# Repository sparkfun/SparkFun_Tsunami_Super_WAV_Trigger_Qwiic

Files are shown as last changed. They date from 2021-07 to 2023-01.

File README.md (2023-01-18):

SparkFun Tsunami Super WAV Trigger (Qwiic)
========================================

<table class="table table-hover table-striped table-bordered">
  <tr align="center">
   <td><a href="https://www.sparkfun.com/products/18159">SparkFun Tsunami Super WAV Trigger (Qwiic) -32 Voices</a></td>
   <td><a href="https://www.sparkfun.com/products/20636">SparkFun Tsunami Super WAV Trigger (Qwiic) - 25 Voices</a></td>
  </tr>
  <tr align="center">
   <td><i>SparkFun Tsunami Super WAV Trigger (Qwiic)<br /> - 32 Voices <br />[ <a href="https://www.sparkfun.com/products/18159">WIG-18159</a> ]</i></td>
   <td><i>SparkFun Tsunami Super WAV Trigger (Qwiic)<br /> - 25 Voices <br />[ <a href="https://www.sparkfun.com/products/20636">WIG-20636</a> ]</i></td>
  </tr>
</table>

Tsunami is a polyphonic Wav file player with 4 stereo (or 8 mono) outputs.  Wav files can be triggered using the 16 onboard contacts, via MIDI, serial connection or Qwiic to a PC or other microcontroller.

Repository Contents
-------------------

* **/Documentation** - Data sheets, additional product information
* **/Hardware** - Eagle design files (.brd, .sch)
* **/Production** - Production panel files (.brd)
* **/Example_WAV_files/MONO** - example WAV Files for use with _mono_ firmware and the [Qwiic Arduino Library Examples](https://github.com/sparkfun/SparkFun_Tsunami_Qwiic_Arduino_Library).
* **/Example_WAV_files/STEREO** - example WAV Files for use with _stereo_ firmware

Documentation
--------------
* **[Hookup Guide](https://learn.sparkfun.com/tutorials/tsunami-super-wav-trigger-hookup-guide)** - Basic hookup guide for Tsunami Qwiic.
* **[Official User Guide](https://cdn.sparkfun.com/assets/e/9/9/8/e/Tsunami_UserGuide_20230114.pdf)** - More detailed user guide, written by Robertsonics.
* **[Official Downloads Page](http://robertsonics.com/downloads/)** - Download supporting files, including firmware updates and the configuration utility.
* **[SparkFun Tsunami Qwiic Arduino Library](https://github.com/sparkfun/SparkFun_Tsunami_Qwiic_Arduino_Library)** - Arduino Library for I2C control via Qwiic cable.
* **[Tsunami Arduino Serial Library](https://github.com/robertsonics/Tsunami-Arduino-Serial-Library)** - Arduino Library for Serial interface control via RX/TX.
* **[SparkFun Fritzing repo](https://github.com/sparkfun/Fritzing_Parts/blob/main/products/13810_Tsunami_Super_WAV_Trigger.fzpz)** - Fritzing diagrams for SparkFun products.
* **[SparkFun 3D Model repo](https://github.com/sparkfun/3D_Models)** - 3D models of SparkFun products.

Product Versions
----------------
* [WIG-20636](https://www.sparkfun.com/products/20636) - v21 with ATSAMS70N19, 25 Voices, and Qwiic supported! 
* [WIG-18159](https://www.sparkfun.com/products/18159) - v21 with ATSAMS70N20, 32 Voices, and Qwiic supported! 
* [WIG-13810](https://www.sparkfun.com/products/13810) - v11 First hardware revision (non-qwiic)

Version History
---------------
* [v21 Production Release](https://github.com/sparkfun/SparkFun_Tsunami_Super_WAV_Trigger_Qwiic/commit/4bed2473d8b69c6fbc46fcfe248d6b1637192635) - V21 hardware revision. There are different versions of this board that use the same PCB. To distinguish the two, check out the IC: ATSAMS70N20 for 32 voices and ATSAMS70N19 for 25 voices.
* [v11 Initial production Release](https://github.com/sparkfun/tsunami/commit/f42b14d72773535e83374cde73f2ca3f25164abb) - V11 hardware revision.

License Information
-------------------

The hardware design of Tsunami is _**open source**_!

Please review the LICENSE.md file for license information.

If you have any questions or concerns on licensing, please contact techsupport@sparkfun.com.

Distributed as-is; no warranty is given.

- Your friends at SparkFun.

Authors
----

Jamie Robertson @ Robertsonics, 
Pete Lewis @ SparkFun Electronics, 
Byron Jacquot @ SparkFun Electronics

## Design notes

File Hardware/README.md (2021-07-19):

SparkFun <PRODUCT NAME> Design Files
=====================================

The .sch and .brd files hare are Eagle CAD schematic and PCB design files from SparkFun Electronics.
A freeware version of Eagle can be found [here](http://www.cadsoftusa.com/download-eagle/freeware/).

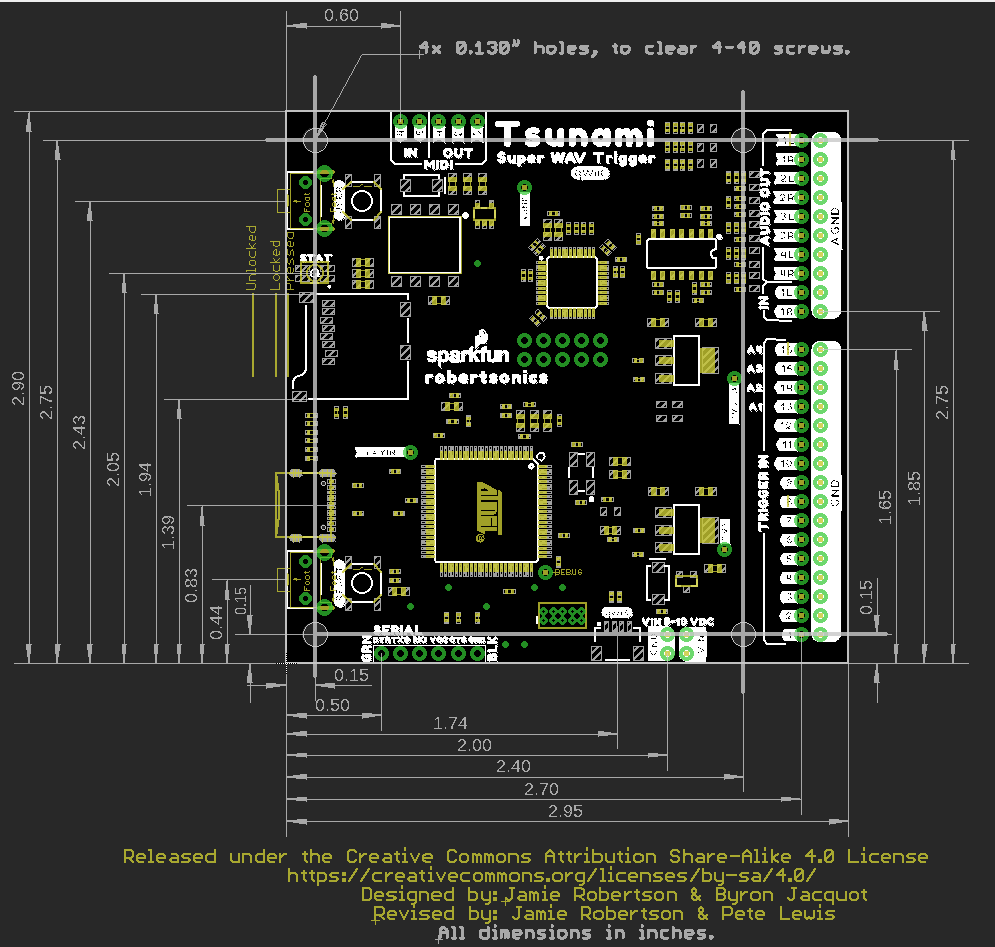
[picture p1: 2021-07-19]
Documents/SparkFun_Tsunami_Qwiic_DIMENSIONS.png

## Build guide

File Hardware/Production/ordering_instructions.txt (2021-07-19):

panel size, 255x162mm
PCB thickness, 1.6mm
number of layers, 2
soldermask color, Red
silkscreen color, White
oz copper, 1oz
finish, HASL lead free
stencils, top
pcs per panel, 6
min trace width, 0.2032mm / 0.0080in
min drill size, 0.3048mm / 0.0120in

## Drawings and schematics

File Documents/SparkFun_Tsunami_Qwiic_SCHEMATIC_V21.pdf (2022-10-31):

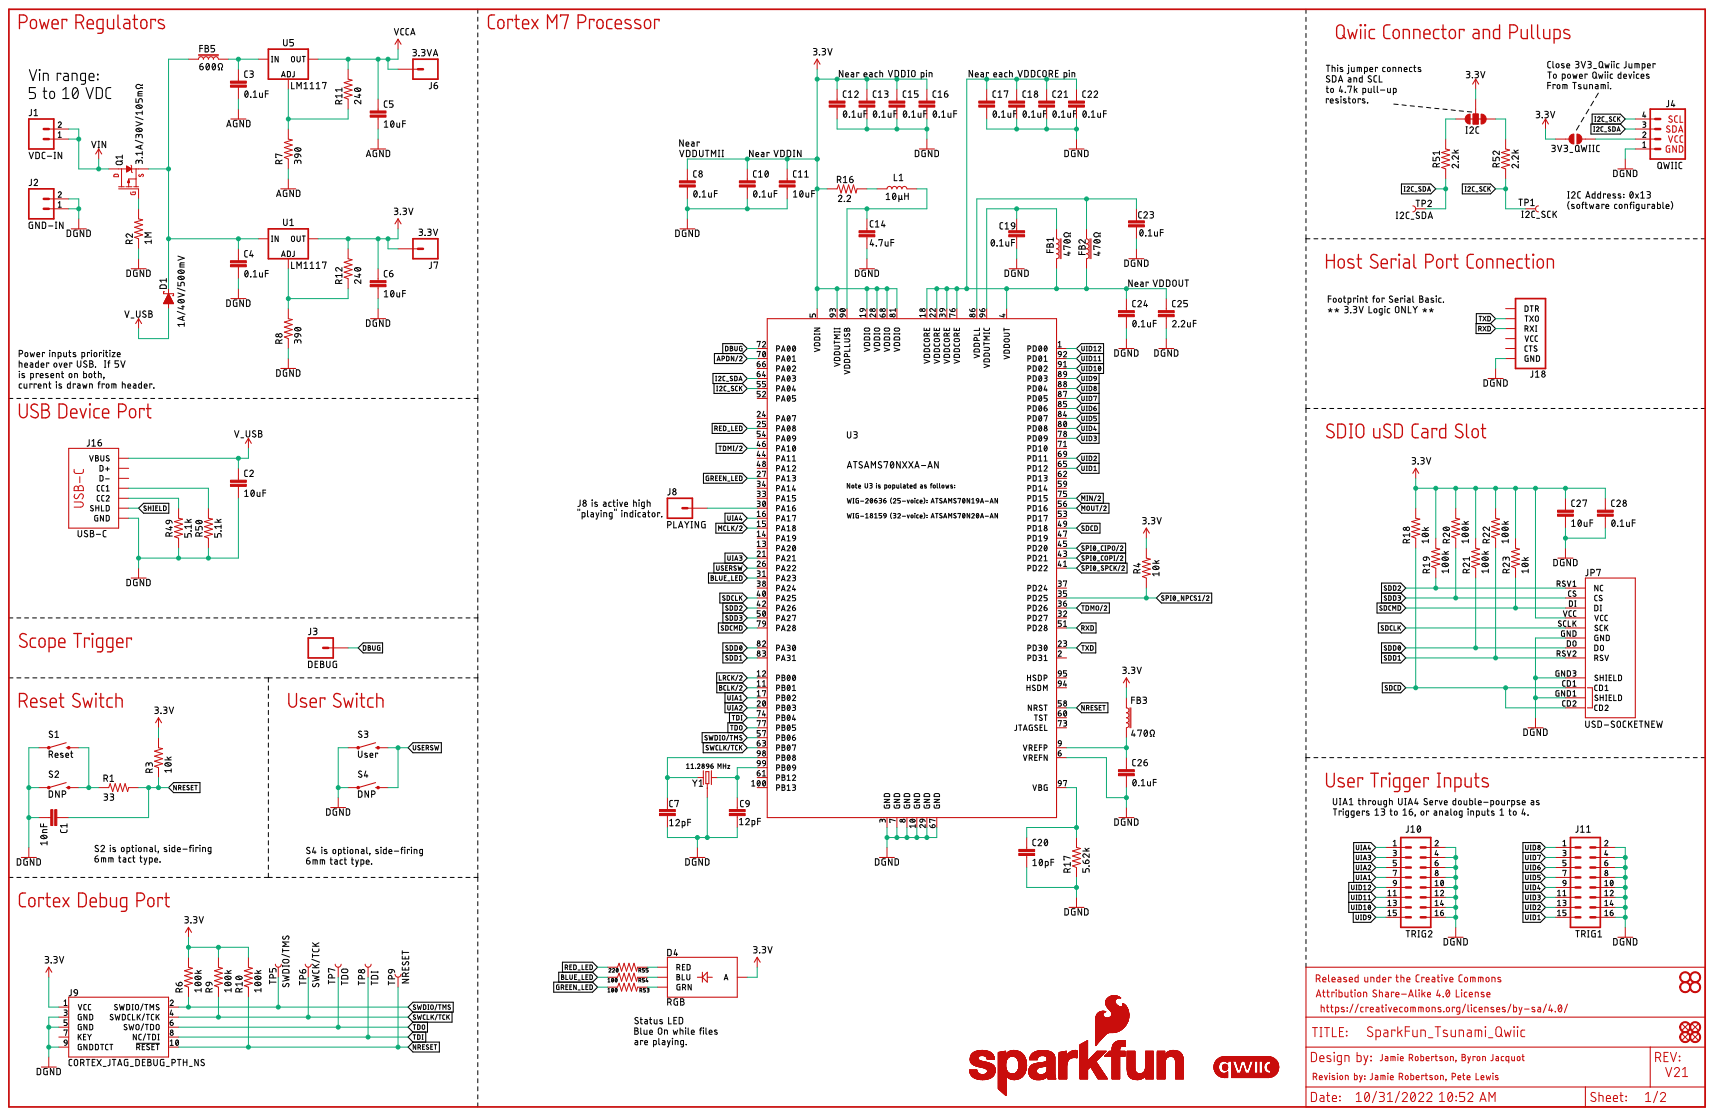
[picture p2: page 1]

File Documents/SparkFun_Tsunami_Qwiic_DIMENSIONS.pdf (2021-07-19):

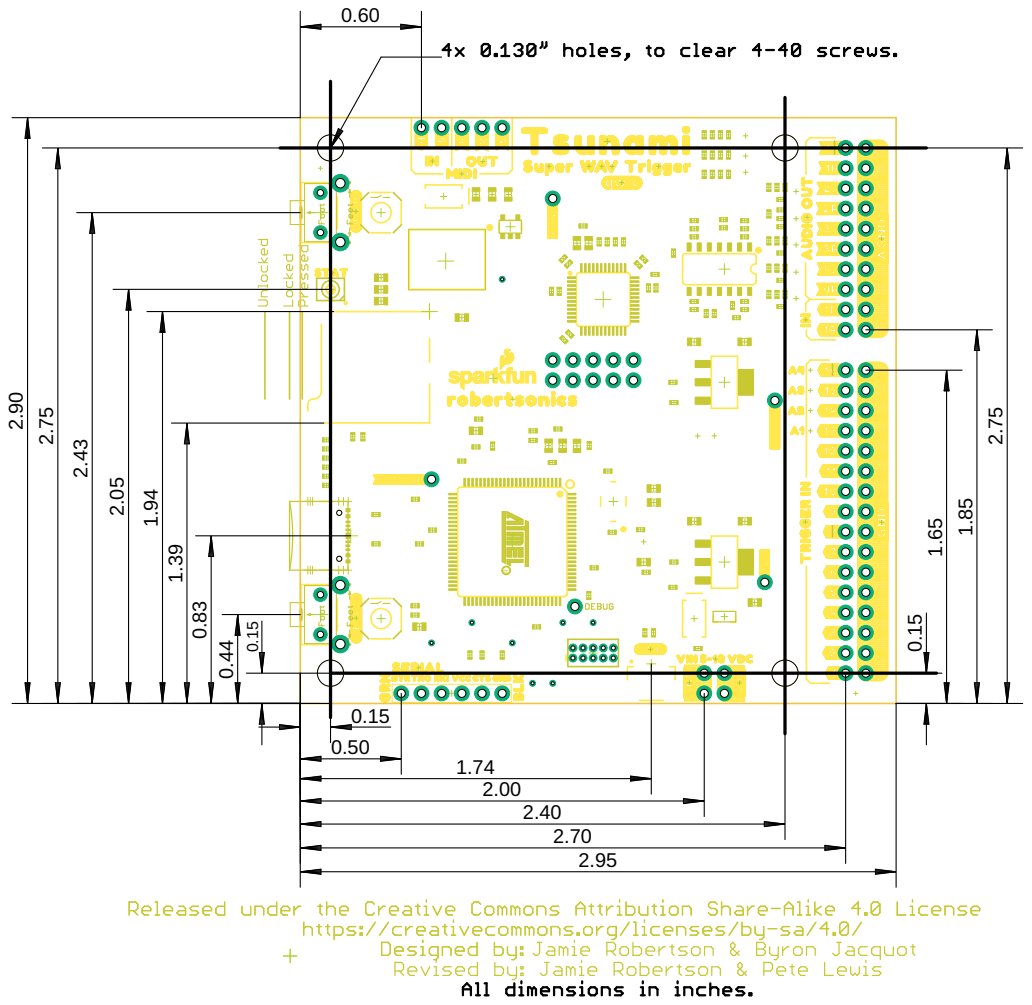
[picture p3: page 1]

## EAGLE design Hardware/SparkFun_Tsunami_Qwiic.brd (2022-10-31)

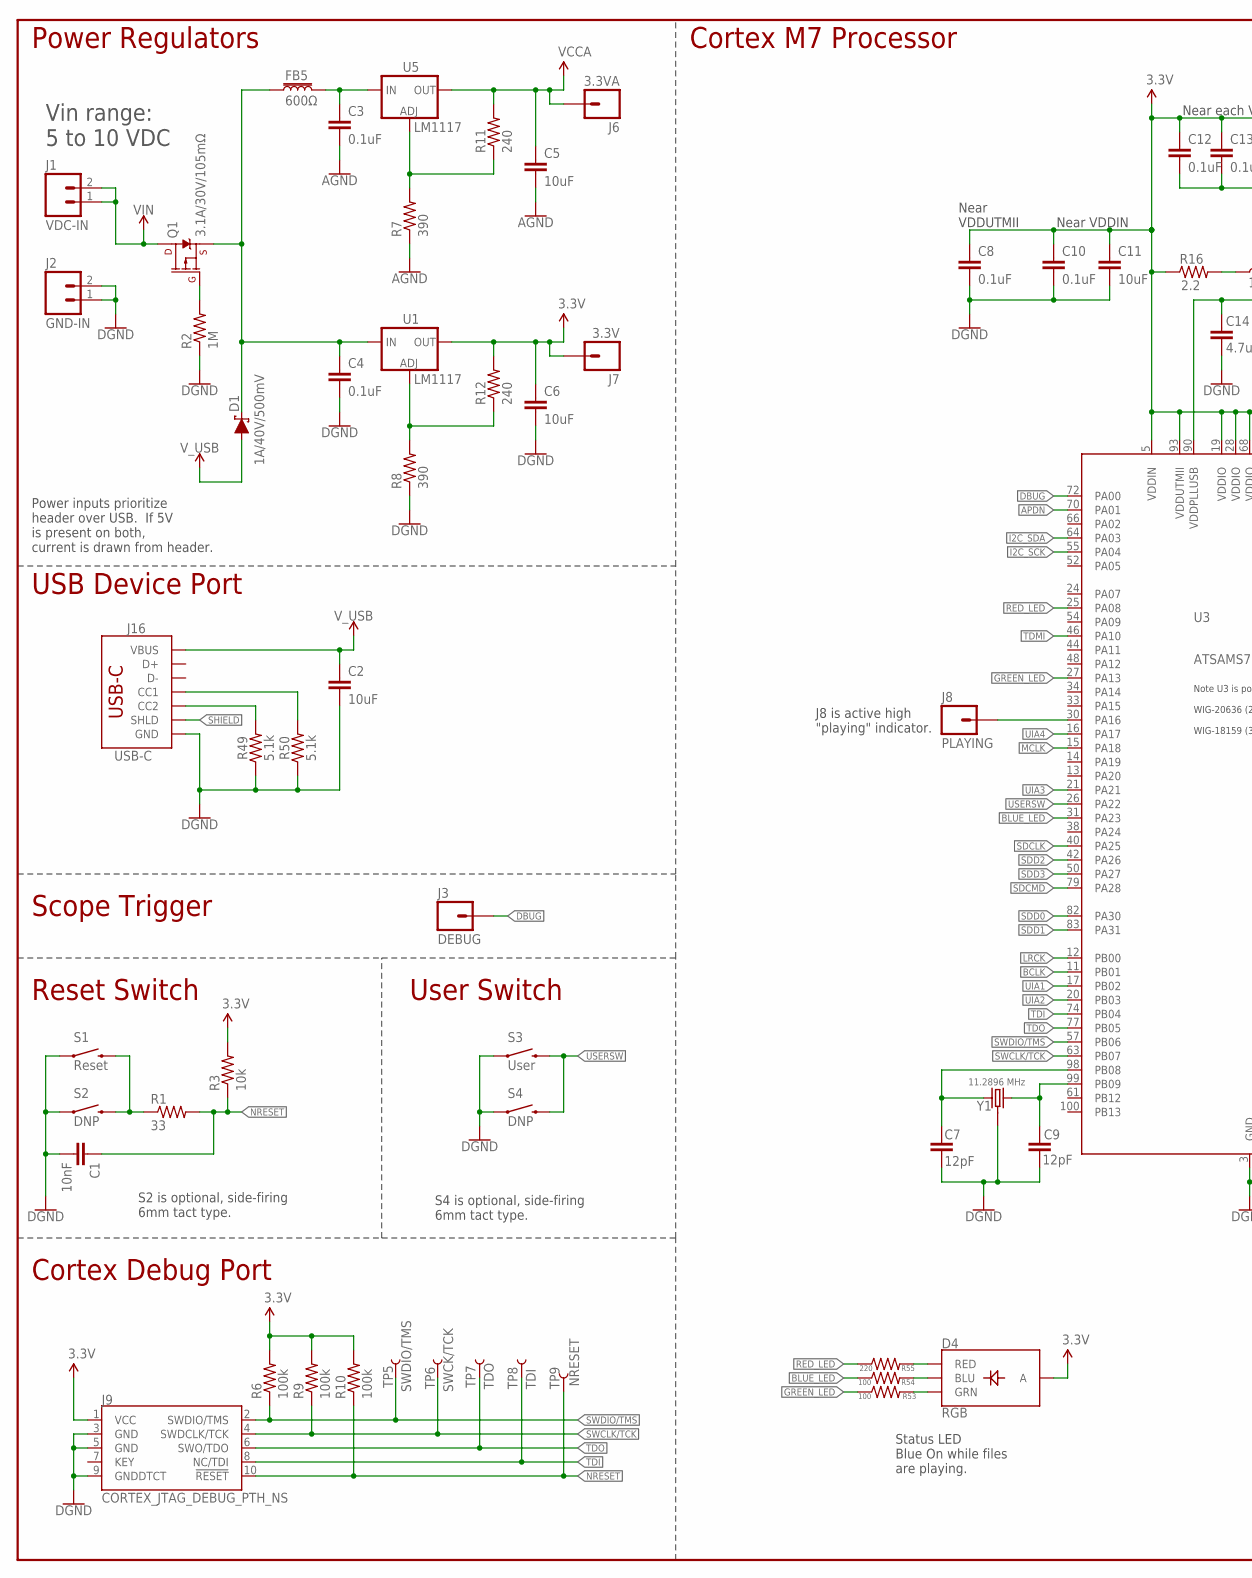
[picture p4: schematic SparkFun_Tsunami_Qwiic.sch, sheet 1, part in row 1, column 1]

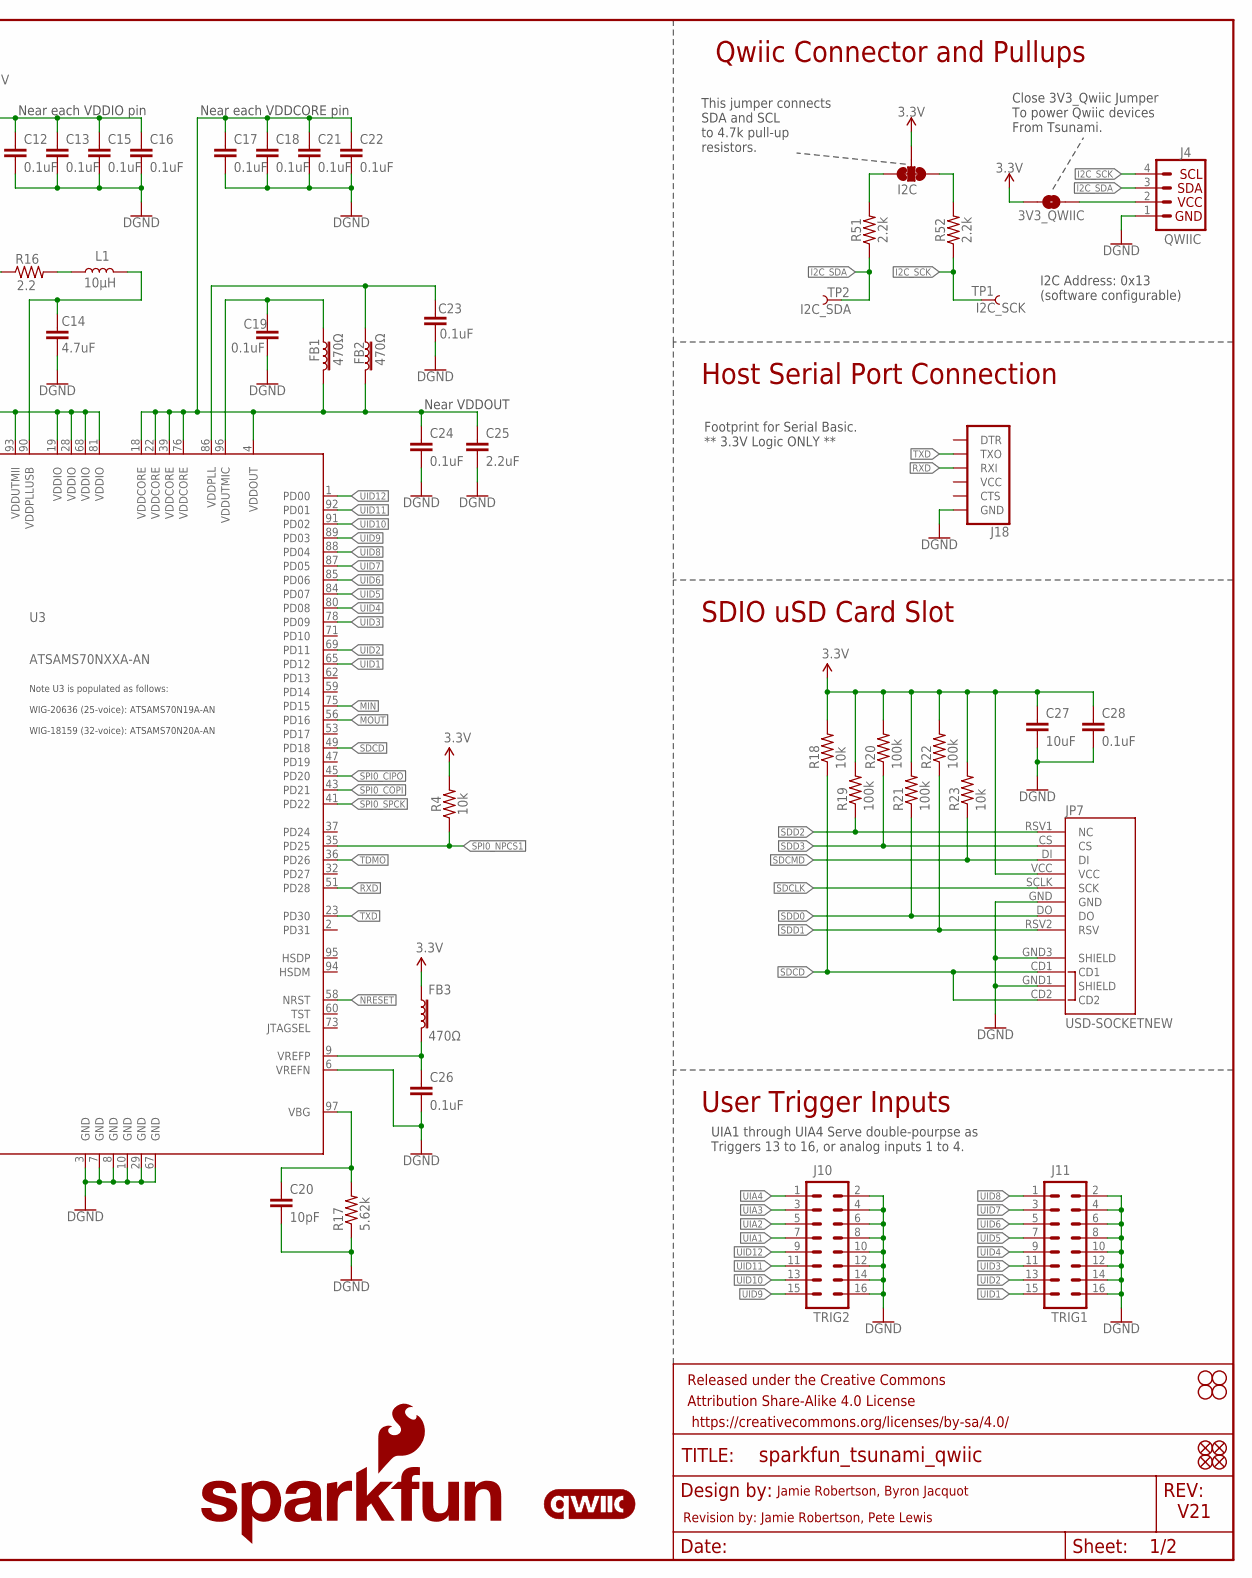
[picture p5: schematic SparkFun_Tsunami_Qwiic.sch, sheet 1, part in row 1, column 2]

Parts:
3V3_QWIIC: JUMPER-SMT_2_NO_SILK; SMT-JUMPER_2_NO_SILK
C1: 10nF; 0402-TIGHT
C2, C5, C6, C11, C27: 10uF; 0402-TIGHT
C3, C4, C8, C10, C12, C13, C15, C16, C17, C18, C19, C21, C22, C23, C24, C26, C28: 0.1uF; 0402-TIGHT
C7, C9: 12pF; 0402-TIGHT
C14: 4.7uF; 0402-TIGHT
C20: 10pF; 0603
C25: 2.2uF; 0603
D1: 1A/40V/500mV; SMA-DIODE
D4: RGB; P-LCC-4-3
FB1, FB2, FB3: 470Ω; 0603
FB5: 600Ω; 0805
FD1, FD2, FD3, FD4: FIDUCIALUFIDUCIAL; FIDUCIAL-MICRO
FRAME1: FRAME-LEDGER; CREATIVE_COMMONS
H1, H2, H3, H4: STAND-OFF
I2C: JUMPER-SMT_3_2-NC_TRACE_SILK; SMT-JUMPER_3_2-NC_TRACE_SILK
J1: VDC-IN; 1X02_NO_SILK
J2: GND-IN; 1X02_NO_SILK
J3: DEBUG; 1X01_NO_SILK
J4: QWIIC; JST04_1MM_RA
J6: 3.3VA; 1X01_NO_SILK
J7: 3.3V; 1X01_NO_SILK
J8: PLAYING; 1X01_NO_SILK
J9: CORTEX_JTAG_DEBUG_PTH_NS; 2X5-PTH-1.27MM-NO_SILK
J10: TRIG2; 2X8_NOSILK
J11: TRIG1; 2X8_NOSILK
J16: USB-C; USB-C-16P-4LAYER-ISOLATED
J18: 6_PIN_SERIAL_TARGETSILK; 6_PIN_SERIAL_TARGET_SIDE_W_SILK
JP7: USD-SOCKETNEW; MICRO-SD-SOCKET-PP
L1: 10μH; 0805
LOGO2: SFE_LOGO_NAME_FLAME.2_INCH; SFE_LOGO_NAME_FLAME_.2
LOGO3: QWIIC_LOGO_4MM; QWIIC_4MM
Q1: 3.1A/30V/105mΩ; SOT23-3
R1: 33; 0603
R2: 1M; 0603
R3, R4, R18, R23: 10k; 0402-TIGHT
R6, R9, R10, R19, R20, R21, R22: 100k; 0402-TIGHT
R7, R8: 390; 0603
R11, R12: 240; 0603
R16: 2.2; 0603
R17: 5.62k; 0603
R49, R50: 5.1k; 0402-TIGHT
R51, R52: 2.2k; 0402-TIGHT
R53, R54: 100; 0603
R55: 220; 0603
S1: Reset; TACTILE_SWITCH_SMD_5.2MM
S2, S4: DNP; TACTILE_SWITCH_PTH_RIGHT_ANGLE
S3: User; TACTILE_SWITCH_SMD_5.2MM
TP1: I2C_SCK; TP_15TH
TP2: I2C_SDA; TP_15TH
TP5: SWDIO/TMS; TP_15TH
TP6: SWCK/TCK; TP_15TH
TP7: TDO; TP_15TH
TP8: TDI; TP_15TH
TP9: NRESET; TP_15TH
U1, U5: LM1117; SOT223
U3: ATSAMS70NXXA-AN; LQFP100
Y1: 11.2896 MHz; CRYSTAL-OSC-SMD-5X3

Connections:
3.3V: 3V3_QWIIC.1, C6.1, C8.1, C10.1, C11.1, C12.1, C13.1, C15.1, C16.1, C27.1, C28.1, D4.4 (A), FB3.1, I2C.2, J7.1, J9.1 (VCC), JP7.VCC, R3.2, R4.2, R6.2, R9.2, R10.2, R12.2, R16.1, R18.2, R19.2, R20.2, R21.2, R22.2, R23.2, U1.2 (OUT), U1.4 (OUT), U3.5 (VDDIN), U3.19 (VDDIO), U3.28 (VDDIO), U3.68 (VDDIO), U3.81 (VDDIO), U3.93 (VDDUTMII); also elsewhere on the board
AGND: C3.2, C5.2, R7.1; also elsewhere on the board
APDN: U3.70 (PA01); also elsewhere on the board
BCLK: U3.11 (PB01); also elsewhere on the board
BLUE_LED: R54.1, U3.31 (PA23)
CC1: J16.A5 (CC1), R50.2
CC2: J16.B5 (CC2), R49.2
DBUG: J3.1, U3.72 (PA00)
DGND: C1.2, C2.2, C4.2, C6.2, C7.2, C8.2, C9.2, C10.2, C11.2, C12.2, C13.2, C14.2, C15.2, C16.2, C17.2, C18.2, C19.2, C20.2, C21.2, C22.2, C23.2, C24.2, C25.2, C26.2, C27.2, C28.2, J2.1, J2.2, J4.1, J9.3 (GND), J9.5 (GND), J9.9 (GNDDTCT), J10.2, J10.4, J10.6, J10.8, J10.10, J10.12, J10.14, J10.16, J11.2, J11.4, J11.6, J11.8, J11.10, J11.12, J11.14, J11.16, J16.GND, J16.GND2 (GND), J18.6 (GND), JP7.GND, JP7.GND1 (SHIELD), JP7.GND3 (SHIELD), R2.1, R8.1, R17.1, R49.1, R50.1, S1.1, S2.1, S3.1, S4.1, U3.3 (GND), U3.6 (VREFN), U3.7 (GND), U3.8 (GND), U3.10 (GND), U3.29 (GND), U3.67 (GND), Y1.2 (3), Y1.4 (3); also elsewhere on the board
GREEN_LED: R53.1, U3.27 (PA13)
I2C_SCK: J4.4, R52.1, TP1.1, U3.55 (PA04)
I2C_SDA: J4.3, R51.1, TP2.1, U3.64 (PA03)
LRCK: U3.12 (PB00); also elsewhere on the board
MCLK: U3.15 (PA18); also elsewhere on the board
MIN: U3.75 (PD15); also elsewhere on the board
MOUT: U3.56 (PD16); also elsewhere on the board
unnamed: C7.1, U3.98 (PB08), Y1.1
unnamed: C9.1, U3.99 (PB09), Y1.3 (2)
unnamed: C19.1, FB1.1, U3.96 (VDDUTMIC)
unnamed: C14.1, L1.2, U3.90 (VDDPLLUSB)
unnamed: C23.1, FB2.1, U3.86 (VDDPLL)
unnamed: I2C.3, R51.2
unnamed: J8.1, U3.30 (PA16)
unnamed: I2C.1, R52.2
unnamed: C20.1, R17.2, U3.97 (VBG)
unnamed: C26.1, FB3.2, U3.9 (VREFP)
unnamed: L1.1, R16.2
unnamed: R7.2, R11.1, U5.1 (ADJ)
unnamed: R1.1, S1.3 (2), S2.2
unnamed: R8.2, R12.1, U1.1 (ADJ)
unnamed: 3V3_QWIIC.2, J4.2
unnamed: D4.2 (GRN), R53.2
unnamed: D4.3 (BLU), R54.2
unnamed: D4.1 (RED), R55.2
unnamed: C3.1, FB5.2, U5.3 (IN)
unnamed: Q1.1 (G), R2.2
NRESET: C1.1, J9.10 (!RESET), R1.2, R3.1, R10.1, TP9.1, U3.58 (NRST)
RED_LED: R55.1, U3.25 (PA08)
REGINPUTS: C4.1, D1.C, FB5.1, Q1.2 (S), U1.3 (IN)
RXD: J18.3 (RXI), U3.51 (PD28)
SDCD: JP7.CD1, JP7.CD2, R18.1, U3.49 (PD18)
SDCLK: JP7.SCLK (SCK), U3.40 (PA25)
SDCMD: JP7.DI, R23.1, U3.79 (PA28)
SDD0: JP7.DO, R21.1, U3.82 (PA30)
SDD1: JP7.RSV2 (RSV), R22.1, U3.83 (PA31)
SDD2: JP7.RSV1 (NC), R19.1, U3.42 (PA26)
SDD3: JP7.CS, R20.1, U3.50 (PA27)
SHIELD: J16.SHLD1 (SHLD), J16.SHLD2 (SHLD), J16.SHLD3 (SHLD), J16.SHLD4 (SHLD), J16.SHLD5 (SHLD), J16.SHLD6 (SHLD), J16.SHLD7 (SHLD), J16.SHLD8 (SHLD)
SPI0_CIPO: U3.45 (PD20); also elsewhere on the board
SPI0_COPI: U3.43 (PD21); also elsewhere on the board
SPI0_NPCS1: R4.1, U3.35 (PD25); also elsewhere on the board
SPI0_SPCK: U3.41 (PD22); also elsewhere on the board
SWCLK/TCK: J9.4 (SWDCLK/TCK), R9.1, TP6.1, U3.63 (PB07)
SWDIO/TMS: J9.2 (SWDIO/TMS), R6.1, TP5.1, U3.57 (PB06)
TDI: J9.8 (NC/TDI), TP8.1, U3.74 (PB04)
TDMI: U3.46 (PA10); also elsewhere on the board
TDMO: U3.36 (PD26); also elsewhere on the board
TDO: J9.6 (SWO/TDO), TP7.1, U3.77 (PB05)
TXD: J18.2 (TXO), U3.23 (PD30)
UIA1: J10.7, U3.17 (PB02)
UIA2: J10.5, U3.20 (PB03)
UIA3: J10.3, U3.21 (PA21)
UIA4: J10.1, U3.16 (PA17)
UID1: J11.15, U3.65 (PD12)
UID2: J11.13, U3.69 (PD11)
UID3: J11.11, U3.78 (PD09)
UID4: J11.9, U3.80 (PD08)
UID5: J11.7, U3.84 (PD07)
UID6: J11.5, U3.85 (PD06)
UID7: J11.3, U3.87 (PD05)
UID8: J11.1, U3.88 (PD04)
UID9: J10.15, U3.89 (PD03)
UID10: J10.13, U3.91 (PD02)
UID11: J10.11, U3.92 (PD01)
UID12: J10.9, U3.1 (PD00)
USERSW: S3.3 (2), S4.2, U3.26 (PA22)
VCCA: C5.1, J6.1, R11.2, U5.2 (OUT), U5.4 (OUT); also elsewhere on the board
VDDOUT: C17.1, C18.1, C21.1, C22.1, C24.1, C25.1, FB1.2, FB2.2, U3.4 (VDDOUT), U3.18 (VDDCORE), U3.22 (VDDCORE), U3.39 (VDDCORE), U3.76 (VDDCORE)
VIN: J1.1, J1.2, Q1.3 (D)
V_USB: C2.1, D1.A, J16.VBUS1 (VBUS), J16.VBUS2 (VBUS)

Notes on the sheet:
Jamie Robertson, Byron Jacquot
V21
Near each VDDCORE pin
Near each VDDIO pin
Near VDDUTMII
Near VDDIN
Near VDDOUT
Power Regulators
USB Device Port
Scope Trigger
Cortex Debug Port
Cortex M7 Processor
SDIO uSD Card Slot
User Trigger Inputs
Reset Switch
S2 is optional, side-firing 6mm tact type.
Vin range: 5 to 10 VDC
Status LED Blue On while files are playing.
Power inputs prioritize header over USB. If 5V is present on both, current is drawn from header.
UIA1 through UIA4 Serve double-pourpse as Triggers 13 to 16, or analog inputs 1 to 4.
Host Serial Port Connection
Footprint for Serial Basic. ** 3.3V Logic ONLY **
User Switch
J8 is active high "playing" indicator.
S4 is optional, side-firing 6mm tact type.
This jumper connects SDA and SCL to 4.7k pull-up resistors.
Revision by: Jamie Robertson, Pete Lewis
Qwiic Connector and Pullups
Close 3V3_Qwiic Jumper To power Qwiic devices From Tsunami.
I2C Address: 0x13 (software configurable)
Note U3 is populated as follows: WIG-20636 (25-voice): ATSAMS70N19A-AN WIG-18159 (32-voice): ATSAMS70N20A-AN

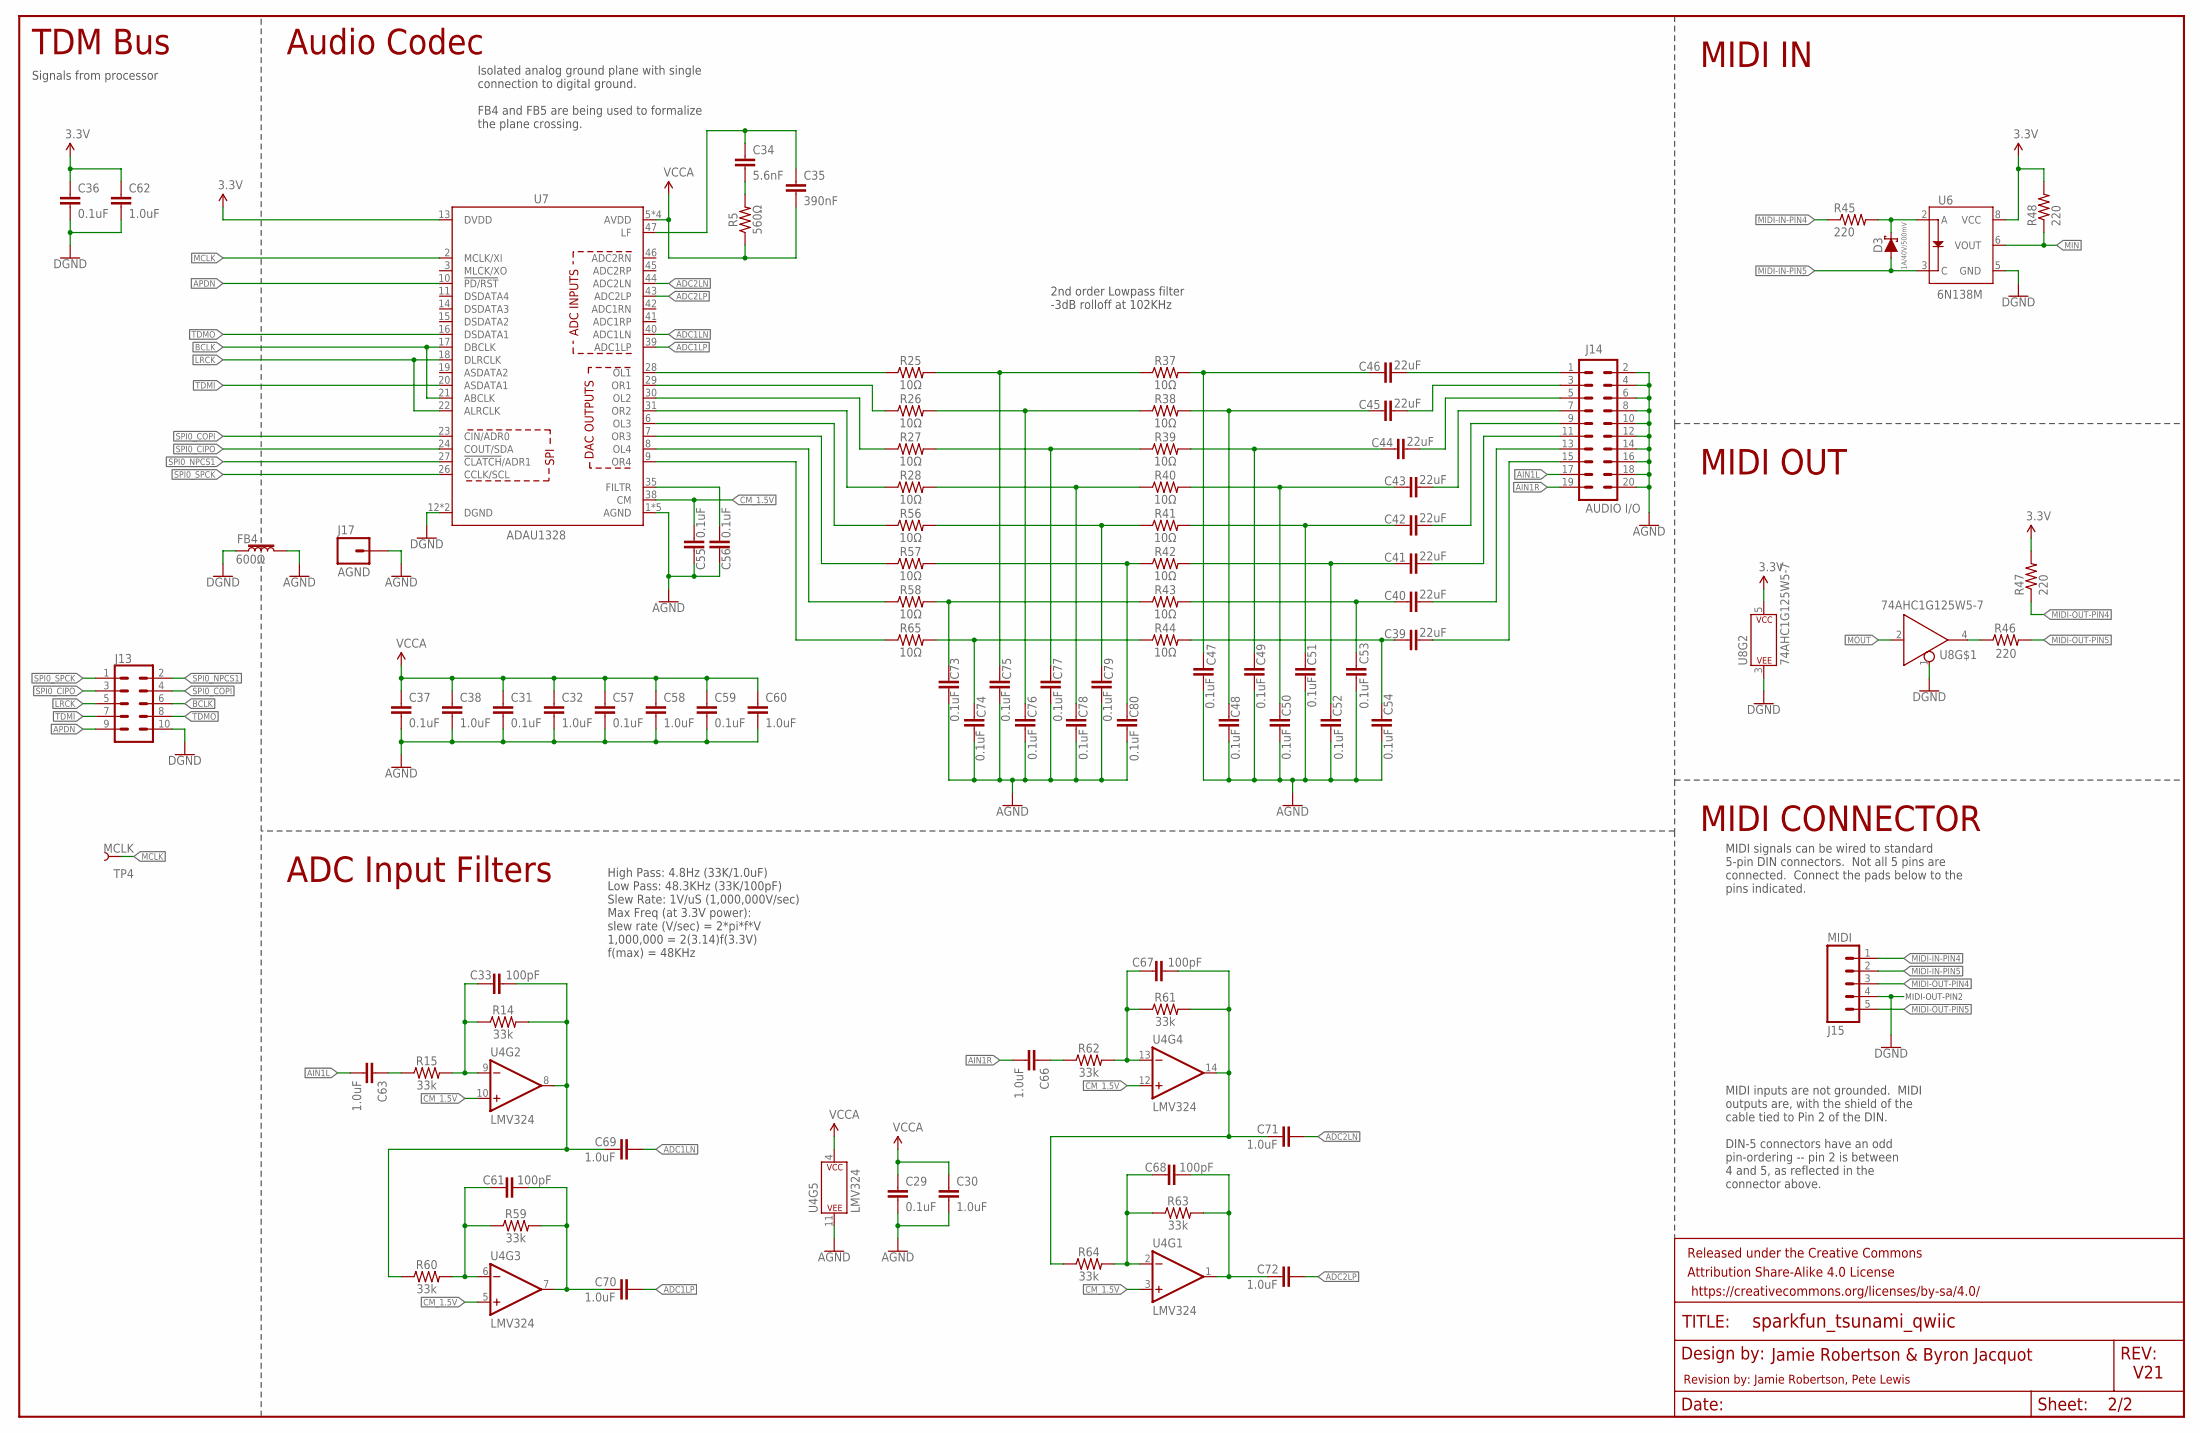
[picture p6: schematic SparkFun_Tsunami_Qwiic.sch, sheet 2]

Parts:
C29, C31, C36, C37, C47, C48, C49, C50, C51, C52, C53, C54, C55, C56, C57, C59, C73, C74, C75, C76, C77, C78, C79, C80: 0.1uF; 0402-TIGHT
C30, C32, C38, C58, C60, C62, C63, C66, C69, C70, C71, C72: 1.0uF; 0402-TIGHT
C33, C61, C67, C68: 100pF; 0402-TIGHT
C34: 5.6nF; 0603
C35: 390nF; 0603
C39, C40, C41, C42, C43, C44, C45, C46: 22uF; 0805
D3: 1A/40V/500mV; SMA-DIODE
FB4: 600Ω; 0805
FRAME2: FRAME-LEDGER; CREATIVE_COMMONS
J13: CONN_05X2NO_SILK; 2X5_NOSILK
J14: AUDIO I/O; 2X10_NOSILK
J15: MIDI; 1X05_NO_SILK
J17: AGND; 1X01_NO_SILK
R5: 560Ω; 0402-TIGHT
R14, R15, R59, R60, R61, R62, R63, R64: 33k; 0402-TIGHT
R25, R26, R27, R28, R37, R38, R39, R40, R41, R42, R43, R44, R56, R57, R58, R65: 10Ω; 0402-TIGHT
R45, R46, R47, R48: 220; 0603
TP4: MCLK; TP_15TH
U4: LMV324; SO14
U6: 6N138M; 8-SMD
U7: ADAU1328; LQFP-48
U8: 74AHC1G125W5-7; SOT23-5

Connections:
3.3V: C36.1, C62.1, R47.2, R48.2, U6.8 (VCC), U7.13 (DVDD), U8.5 (P$V+); also elsewhere on the board
56: D3.C, R45.2, U6.2 (A)
ADC1LN: C69.1, U7.40 (ADC1LN)
ADC1LP: C70.1, U7.39 (ADC1LP)
ADC2LN: C71.1, U7.44 (ADC2LN)
ADC2LP: C72.1, U7.43 (ADC2LP)
AGND: C29.2, C30.2, C31.2, C32.2, C37.2, C38.2, C47.2, C48.2, C49.2, C50.2, C51.2, C52.2, C53.2, C54.2, C55.2, C56.2, C57.2, C58.2, C59.2, C60.2, C73.1, C74.1, C75.1, C76.1, C77.1, C78.1, C79.1, C80.1, FB4.2, J14.2, J14.4, J14.6, J14.8, J14.10, J14.12, J14.14, J14.16, J14.18, J14.20, J17.1, U4.11 (P$V-), U7.1 (AGND), U7.4 (AGND), U7.32 (AGND), U7.34 (AGND), U7.36 (AGND); also elsewhere on the board
AIN1L: C63.2, J14.17
AIN1R: C66.2, J14.19
AOUT1L: C46.1, C47.1, R37.2
AOUT1R: C45.1, C48.1, R38.2
AOUT2L: C44.2, J14.5
AOUT2R: C43.1, C50.1, R40.2
AOUT3L: C42.2, J14.9
AOUT3R: C41.1, C52.1, R42.2
AOUT4L: C40.1, C53.1, R43.2
AOUT4R: C39.1, C54.1, R44.2
APDN: J13.9, U7.10 (!PD/RST!); also elsewhere on the board
BCLK: J13.6, U7.17 (DBCLK), U7.21 (ABCLK); also elsewhere on the board
CM_1.5V: C55.1, U4.3 (+IN), U4.5 (+IN), U4.10 (+IN), U4.12 (+IN), U7.38 (CM)
DGND: C36.2, C62.2, FB4.1, J13.10, J15.4, U6.5 (GND), U7.12 (DGND), U7.25 (DGND), U8.1 (!EN), U8.3 (P$V-); also elsewhere on the board
LF: C34.1, C35.1, U7.47 (LF)
LRCK: J13.5, U7.18 (DLRCLK), U7.22 (ALRCLK); also elsewhere on the board
MCLK: TP4.1, U7.2 (MCLK/XI); also elsewhere on the board
MIDI-IN-PIN4: J15.1, R45.1
MIDI-IN-PIN5: D3.A, J15.2, U6.3 (C)
MIDI-OUT-PIN4: J15.3, R47.1
MIDI-OUT-PIN5: J15.5, R46.2
MIN: R48.1, U6.6 (VOUT); also elsewhere on the board
MOUT: U8.2 (A); also elsewhere on the board
unnamed: C33.2, C69.2, R14.2, R60.1, U4.8 (OUT)
unnamed: C34.2, R5.2
unnamed: C63.1, R15.1
unnamed: C61.2, C70.2, R59.2, U4.7 (OUT)
unnamed: C68.2, C72.2, R63.2, U4.1 (OUT)
unnamed: C39.2, J14.15
unnamed: C40.2, J14.13
unnamed: C41.2, J14.11
unnamed: C42.1, C51.1, R41.2
unnamed: C43.2, J14.7
unnamed: C75.2, R25.2, R37.1
unnamed: C74.2, R44.1, R65.2
unnamed: C73.2, R43.1, R58.2
unnamed: C80.2, R42.1, R57.2
unnamed: C44.1, C49.1, R39.2
unnamed: C46.2, J14.1
unnamed: C45.2, J14.3
unnamed: R46.1, U8.4 (Y)
unnamed: C56.1, U7.35 (FILTR)
unnamed: C61.1, R59.1, R60.2, U4.6 (-IN)
unnamed: C33.1, R14.1, R15.2, U4.9 (-IN)
unnamed: C79.2, R41.1, R56.2
unnamed: C78.2, R28.2, R40.1
unnamed: C76.2, R26.2, R38.1
unnamed: C77.2, R27.2, R39.1
unnamed: C67.2, C71.2, R61.2, R64.1, U4.14 (OUT)
unnamed: C66.1, R62.1
unnamed: C68.1, R63.1, R64.2, U4.2 (-IN)
unnamed: C67.1, R61.1, R62.2, U4.13 (-IN)
OL1: R25.1, U7.28 (OL1)
OL2: R27.1, U7.30 (OL2)
OL3: R56.1, U7.6 (OL3)
OL4: R58.1, U7.8 (OL4)
OR1: R26.1, U7.29 (OR1)
OR2: R28.1, U7.31 (OR2)
OR3: R57.1, U7.7 (OR3)
OR4: R65.1, U7.9 (OR4)
SPI0_CIPO: J13.3, U7.24 (COUT/SDA); also elsewhere on the board
SPI0_COPI: J13.4, U7.23 (CIN/ADR0); also elsewhere on the board
SPI0_NPCS1: J13.2, U7.27 (!CLATCH!/ADR1); also elsewhere on the board
SPI0_SPCK: J13.1, U7.26 (CCLK/SCL); also elsewhere on the board
TDMI: J13.7, U7.20 (ASDATA1); also elsewhere on the board
TDMO: J13.8, U7.16 (DSDATA1); also elsewhere on the board
VCCA: C29.1, C30.1, C31.1, C32.1, C35.2, C37.1, C38.1, C57.1, C58.1, C59.1, C60.1, R5.1, U4.4 (P$V+), U7.5 (AVDD), U7.33 (AVDD), U7.37 (AVDD), U7.48 (AVDD); also elsewhere on the board

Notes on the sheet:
Isolated analog ground plane with single connection to digital ground. FB4 and FB5 are being used to formalize the plane crossing.
Audio Codec
MIDI IN
MIDI OUT
Jamie Robertson & Byron Jacquot
V21
TDM Bus
Signals from processor
MIDI CONNECTOR
MIDI signals can be wired to standard 5-pin DIN connectors. Not all 5 pins are connected. Connect the pads below to the pins indicated.
MIDI-OUT-PIN2
MIDI inputs are not grounded. MIDI outputs are, with the shield of the cable tied to Pin 2 of the DIN. DIN-5 connectors have an odd pin-ordering -- pin 2 is between 4 and 5, as reflected in the connector above.
2nd order Lowpass filter -3dB rolloff at 102KHz
ADC Input Filters
High Pass: 4.8Hz (33K/1.0uF) Low Pass: 48.3KHz (33K/100pF) Slew Rate: 1V/uS (1,000,000V/sec) Max Freq (at 3.3V power): slew rate (V/sec) = 2*pi*f*V 1,000,000 = 2(3.14)f(3.3V) f(max) = 48KHz
Revision by: Jamie Robertson, Pete Lewis

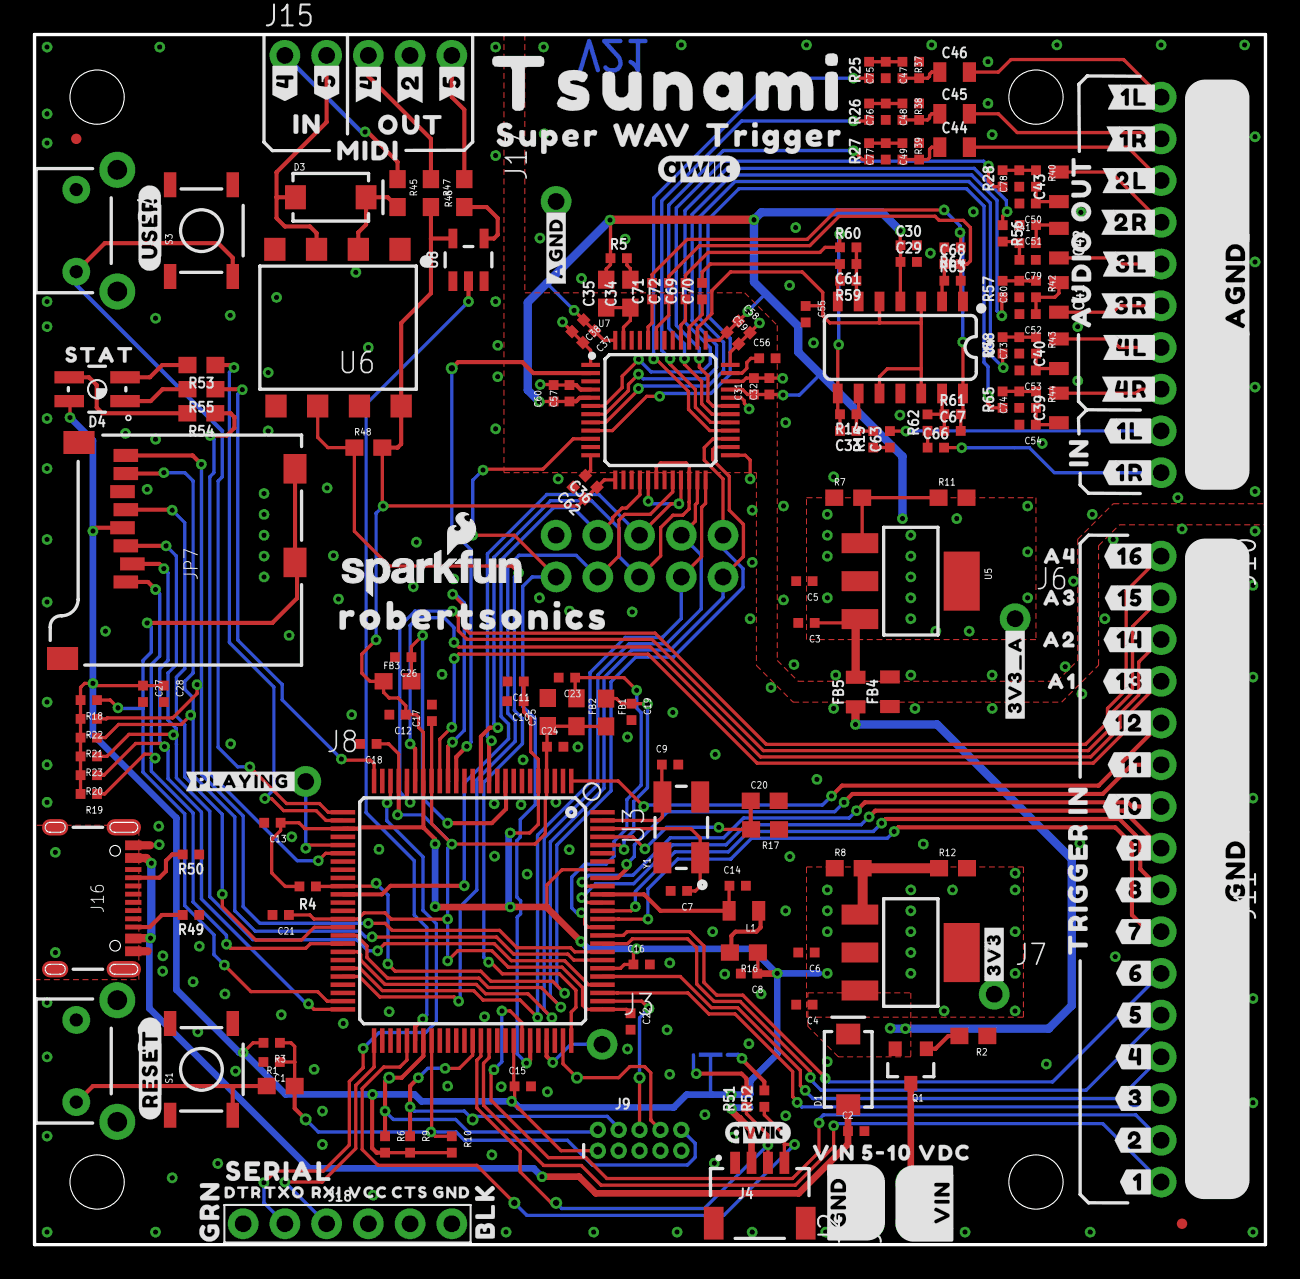
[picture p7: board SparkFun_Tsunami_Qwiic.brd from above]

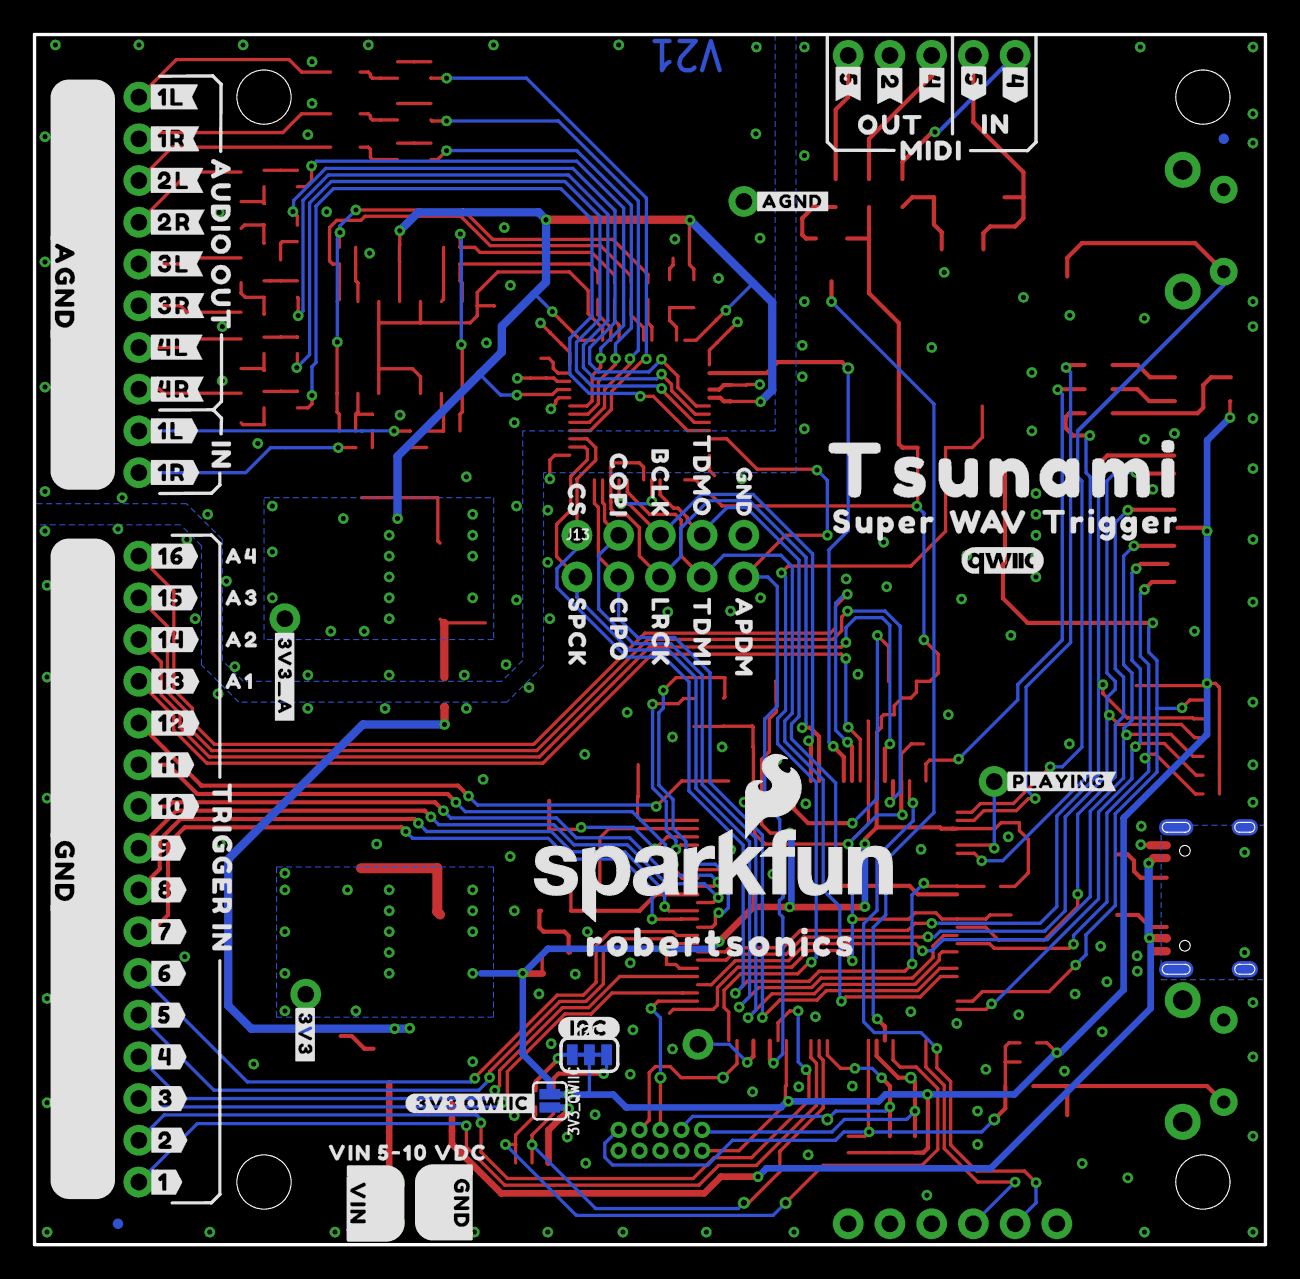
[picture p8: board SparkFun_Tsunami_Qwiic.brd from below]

Board: 2 copper layers, 74.9 x 73.7 mm, 327 parts (76 on the bottom side), 138 nets.

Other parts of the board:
U$3: GND_0
U$4, U$73: QWIIC_5MM
U$5: STAT0
U$6: #USER#0
U$7: #RESET#0
U$8, U$9: ROBERTSONICS0
U$10, U$167: #2L#0
U$11: #1L#0
U$12, U$120: #1R#0
U$13: #2R#0
U$14: #3R#0
U$15: #3L#0
U$16: #4L#0
U$17: #4R#0
U$18: #4#3
U$19: #2#5
U$20, U$107: AUDIO_OUT0
U$21, U$46, U$108, U$123: IN0
U$22, U$106: TRIGGER_IN0
U$23, U$85: #GND#0
U$24: #1#0
U$25: SERIAL3
U$26, U$60: SUPER0
U$27, U$99: VIN_5#10_VDC0
U$28, U$84: #AGND#0
U$29: #2#0
U$30: #3#0
U$31, U$56, U$117: #4#0
U$32, U$58, U$118: #5#0
U$33: #6#0
U$34: #7#0
U$35: #8#0
U$36: #9#0
U$37: #10#0
U$38: #11#0
U$39: #12#0
U$40: #PLAYING#30
U$41, U$112: #3V3#0
U$43: #13#0
U$44: #3V3_A#0
U$45, U$122: MIDI0
U$47, U$124: OUT0
U$48: #14#0
U$49: #15#0
U$50: #16#0
U$51: A10
U$52: A20
U$53: A30
U$54: A40
U$55: #5#6
U$57: #2#6
U$59: #4#6
U$61, U$110: #GND#1
U$62, U$68: TRIGGER0
U$63, U$69: TSUNAMI0
U$64, U$70: W0
U$65, U$71: A0
U$66, U$72: V0
U$67, U$111: #VIN#2
U$74: #16#5
U$75: #15#17
U$76: #14#17
U$77: #13#17
U$78: #12#17
U$79: #11#17
U$80: #10#17
U$81: #9#17
U$82: #8#17
U$83: #7#17
U$86: CS17
U$87: BCLK19
U$88: COPI18
U$89: TDMO20
U$91: SPCK22
U$92: TDMI25
U$93: LRCK24
U$94: CIPO23
U$95: APDM26
U$96: #AGND#27
U$97: #AGND#28
U$98: #PLAYING#29
U$102: A117
U$103: A2118
U$104: A32119
U$105: A432120
U$113: #I2C#6
U$116: #1L#3
U$119: #1L#6
U$121: #1R#2
U$141: SFE_LOGO_NAME_FLAME_.1
U$162: #3V3_A#4
U$163: #3V3_QWIIC#0
U$164: #1R#3
U$165: #5#5
U$166: #1L#2
U$168: #2R#3
U$169: #3L#3
U$170: #3R#4
U$171: #4L#4
U$172: #4R#5
U$173: #6#17
U$174: #5#17
U$175: #4#17
U$176: #3#17
U$177: #2#17
U$178: #1#17

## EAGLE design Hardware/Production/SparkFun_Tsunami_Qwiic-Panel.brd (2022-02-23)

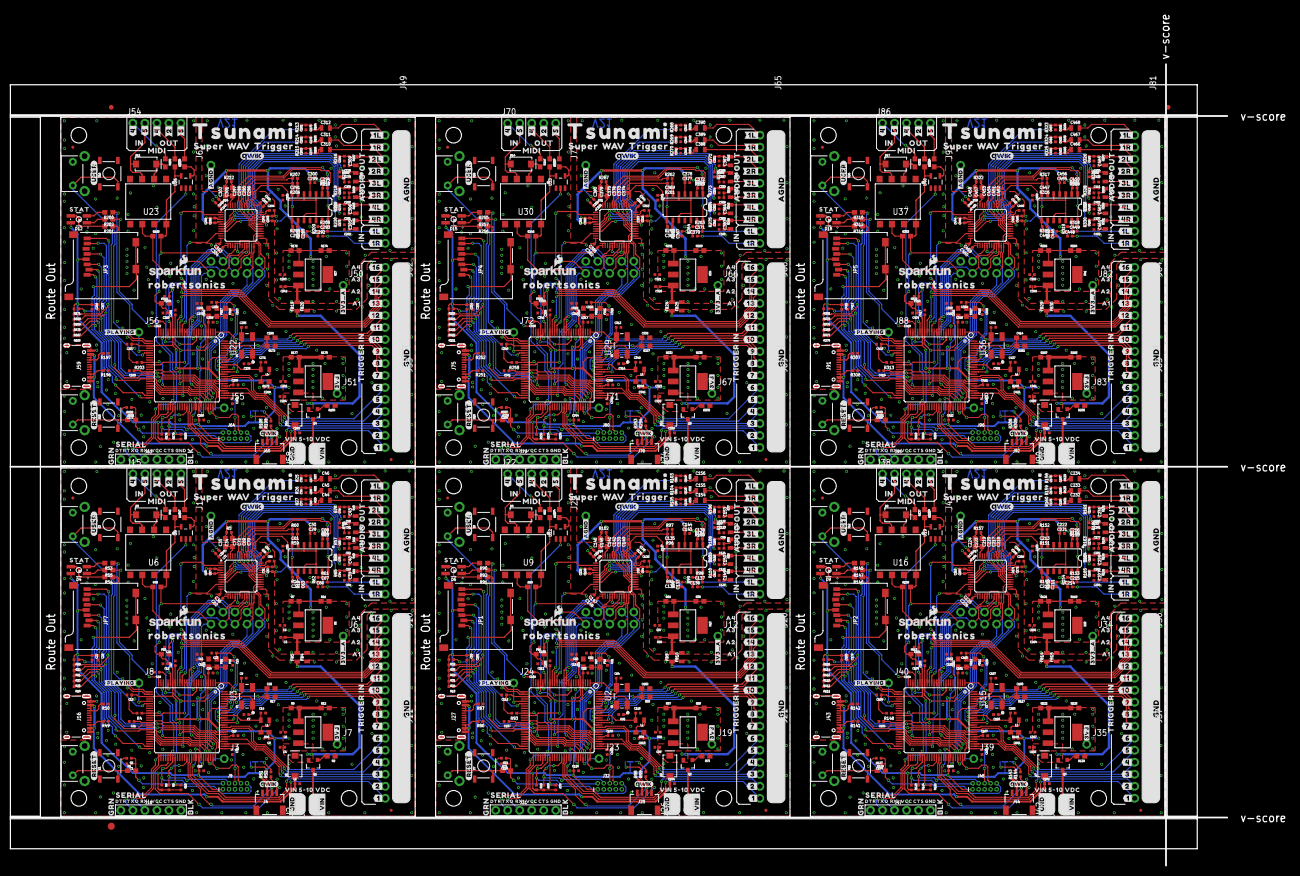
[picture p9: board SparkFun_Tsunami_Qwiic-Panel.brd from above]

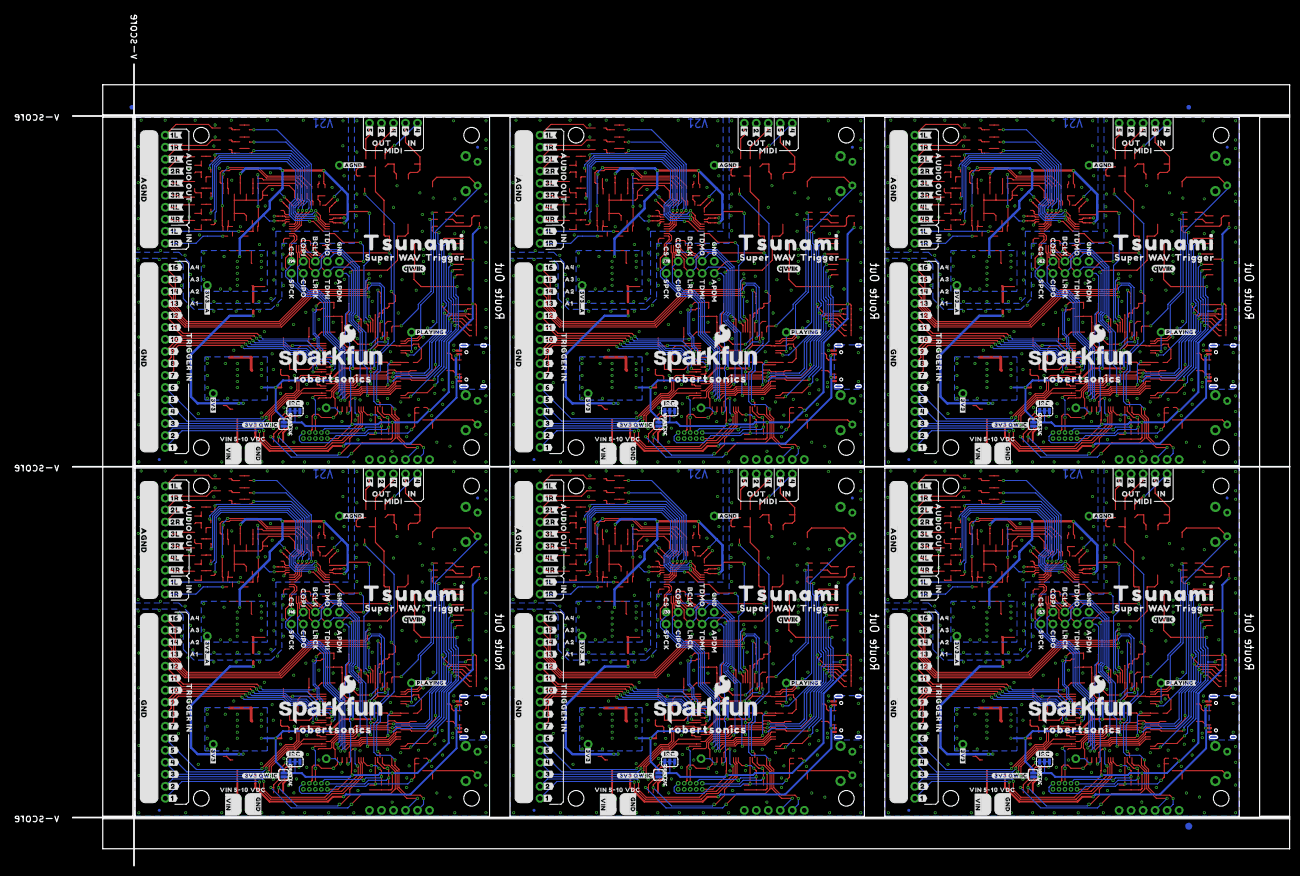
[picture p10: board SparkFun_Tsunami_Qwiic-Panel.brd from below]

Board: 2 copper layers, 257.3 x 169.4 mm, 1956 parts (459 on the bottom side), 828 nets.

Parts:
3V3_QWIIC, 3V3_QWIIC1, 3V3_QWIIC2, 3V3_QWIIC3, 3V3_QWIIC4, 3V3_QWIIC5: SMT-JUMPER_2_NO_SILK
C1, C116, C194, C272, C350, C428: 10nF; 0402-TIGHT
C2, C5, C6, C11, C27, C85, C87, C89, C90, C104, C163, C165, C167, C168, C182, C241, C243, C245, C246, C260, C319, C321, C323, C324, C338, C397, C399, C401, C402, C416: 10uF; 0402-TIGHT
C3, C4, C8, C10, C12, C13, C15, C16, C17, C18, C19, C21, C22, C23, C24, C26, C28, C29, C31, C36, C37, C47, C48, C49, C50, C51, C52, C53, C54, C55, C56, C57, C59, C73, C74, C75, C76, C77, C78, C79, C80, C81, C82, C83, C86, C88, C91, C93, C95, C96, C97, C98, C99, C100, C101, C103, C105, C106, C107, C108, C109, C110, C111, C112, C113, C114, C117, C118, C119, C120, C121, C122, C123, C124, C125, C126, C127, C128, C129, C131, C143, C147, C159, C160, C161, C164, C166, C169, C171, C173, C174, C175, C176, C177, C178, C179, C181, C183, C184, C185, C186, C187, C188, C189, C190, C191, C192, C195, C196, C197, C198, C199, C200, C201, C202, C203, C204, C205, C206, C207, C209, C221, C225, C237, C238, C239, C242, C244, C247, C249, C251, C252, C253, C254, C255, C256, C257, C259, C261, C262, C263, C264, C265, C266, C267, C268, C269, C270, C273, C274, C275, C276, C277, C278, C279, C280, C281, C282, C283, C284, C285, C287, C299, C303, C315, C316, C317, C320, C322, C325, C327, C329, C330, C331, C332, C333, C334, C335, C337, C339, C340, C341, C342, C343, C344, C345, C346, C347, C348, C351, C352, C353, C354, C355, C356, C357, C358, C359, C360, C361, C362, C363, C365, C377, C381, C393, C394, C395, C398, C400, C403, C405, C407, C408, C409, C410, C411, C412, C413, C415, C417, C418, C419, C420, C421, C422, C423, C424, C425, C426, C429, C430, C431, C432, C433, C434, C435, C436, C437, C438, C439, C440, C441, C443, C455, C459: 0.1uF; 0402-TIGHT
C7, C9, C64, C65, C157, C158, C235, C236, C313, C314, C391, C392: 12pF; 0402-TIGHT
C14, C115, C193, C271, C349, C427: 4.7uF; 0402-TIGHT
C20, C102, C180, C258, C336, C414: 10pF; 0603
C25, C84, C162, C240, C318, C396: 2.2uF; 0603
C30, C32, C38, C58, C60, C62, C63, C66, C69, C70, C71, C72, C92, C94, C130, C132, C133, C136, C139, C140, C141, C142, C144, C148, C170, C172, C208, C210, C211, C214, C217, C218, C219, C220, C222, C226, C248, C250, C286, C288, C289, C292, C295, C296, C297, C298, C300, C304, C326, C328, C364, C366, C367, C370, C373, C374, C375, C376, C378, C382, C404, C406, C442, C444, C445, C448, C451, C452, C453, C454, C456, C460: 1.0uF; 0402-TIGHT
C33, C61, C67, C68, C134, C135, C137, C138, C212, C213, C215, C216, C290, C291, C293, C294, C368, C369, C371, C372, C446, C447, C449, C450: 100pF; 0402-TIGHT
C34, C145, C223, C301, C379, C457: 5.6nF; 0603
C35, C146, C224, C302, C380, C458: 390nF; 0603
C39, C40, C41, C42, C43, C44, C45, C46, C149, C150, C151, C152, C153, C154, C155, C156, C227, C228, C229, C230, C231, C232, C233, C234, C305, C306, C307, C308, C309, C310, C311, C312, C383, C384, C385, C386, C387, C388, C389, C390, C461, C462, C463, C464, C465, C466, C467, C468: 22uF; 0805
D1, D2, D3, D5, D7, D8, D10, D11, D13, D14, D16, D17: 1A/40V/500mV; SMA-DIODE
D4, D6, D9, D12, D15, D18: RGB; P-LCC-4-3
E$1, E$2, E$3, E$4: FIDUCIAL-1X2
E$5, E$6: FIDUCIAL-1.5X3
FB1, FB2, FB3, FB6, FB7, FB8, FB11, FB12, FB13, FB16, FB17, FB18, FB21, FB22, FB23, FB26, FB27, FB28: 470Ω; 0603
FB4, FB5, FB9, FB10, FB14, FB15, FB19, FB20, FB24, FB25, FB29, FB30: 600Ω; 0805
FD1, FD2, FD3, FD4, FD5, FD6, FD7, FD8, FD9, FD10, FD11, FD12, FD13, FD14, FD15, FD16, FD17, FD18, FD19, FD20, FD21, FD22, FD23, FD24: FIDUCIALUFIDUCIAL; FIDUCIAL-MICRO
H1, H2, H3, H4, H5, H6, H7, H8, H9, H10, H11, H12, H13, H14, H15, H16, H17, H18, H19, H20, H21, H22, H23, H24: STAND-OFF
I2C, I2C1, I2C2, I2C3, I2C4, I2C5: SMT-JUMPER_3_2-NC_TRACE_SILK
J1, J25, J41, J57, J73, J89: VDC-IN; 1X02_NO_SILK
J2, J26, J42, J58, J74, J90: GND-IN; 1X02_NO_SILK
J3, J23, J39, J55, J71, J87: DEBUG; 1X01_NO_SILK
J4, J28, J44, J60, J76, J92: QWIIC; JST04_1MM_RA
J5, J14, J33, J49, J65, J81: AUDIO I/O; 2X10_NOSILK
J6, J12, J34, J50, J66, J82: 3.3VA; 1X01_NO_SILK
J7, J19, J35, J51, J67, J83: 3.3V; 1X01_NO_SILK
J8, J24, J40, J56, J72, J88: PLAYING; 1X01_NO_SILK
J9, J32, J48, J64, J80, J96: CORTEX_JTAG_DEBUG_PTH_NS; 2X5-PTH-1.27MM-NO_SILK
J10, J20, J36, J52, J68, J84: TRIG2; 2X8_NOSILK
J11, J21, J37, J53, J69, J85: TRIG1; 2X8_NOSILK
J13, J30, J46, J62, J78, J94: 2X5_NOSILK
J15, J22, J38, J54, J70, J86: MIDI; 1X05_NO_SILK
J16, J27, J43, J59, J75, J91: USB-C; USB-C-16P-4LAYER-ISOLATED
J17, J29, J45, J61, J77, J93: AGND; 1X01_NO_SILK
J18, J31, J47, J63, J79, J95: 6_PIN_SERIAL_TARGET_SIDE_W_SILK
JP1, JP2, JP3, JP4, JP5, JP7: USD-SOCKETNEW; MICRO-SD-SOCKET-PP
L1, L2, L3, L4, L5, L6: 10μH; 0805
LOGO1, LOGO3, LOGO5, LOGO7, LOGO9, LOGO11: QWIIC_LOGO_4MM; QWIIC_4MM
LOGO2, LOGO4, LOGO6, LOGO8, LOGO10, LOGO12: SFE_LOGO_NAME_FLAME.2_INCH; SFE_LOGO_NAME_FLAME_.2
Q1, Q2, Q3, Q4, Q5, Q6: 3.1A/30V/105mΩ; SOT23-3
R1, R71, R126, R181, R236, R291: 33; 0603
R2, R73, R128, R183, R238, R293: 1M; 0603
R3, R4, R18, R23, R31, R32, R72, R93, R115, R116, R127, R148, R170, R171, R182, R203, R225, R226, R237, R258, R280, R281, R292, R313: 10k; 0402-TIGHT
R5, R102, R157, R212, R267, R322: 560Ω; 0402-TIGHT
R6, R9, R10, R13, R19, R20, R21, R22, R24, R29, R30, R68, R69, R70, R111, R112, R113, R114, R123, R124, R125, R166, R167, R168, R169, R178, R179, R180, R221, R222, R223, R224, R233, R234, R235, R276, R277, R278, R279, R288, R289, R290: 100k; 0402-TIGHT
R7, R8, R66, R67, R121, R122, R176, R177, R231, R232, R286, R287: 390; 0603
R11, R12, R35, R36, R119, R120, R174, R175, R229, R230, R284, R285: 240; 0603
R14, R15, R59, R60, R61, R62, R63, R64, R94, R95, R96, R97, R98, R99, R100, R101, R149, R150, R151, R152, R153, R154, R155, R156, R204, R205, R206, R207, R208, R209, R210, R211, R259, R260, R261, R262, R263, R264, R265, R266, R314, R315, R316, R317, R318, R319, R320, R321: 33k; 0402-TIGHT
R16, R34, R118, R173, R228, R283: 2.2; 0603
R17, R33, R117, R172, R227, R282: 5.62k; 0603
R25, R26, R27, R28, R37, R38, R39, R40, R41, R42, R43, R44, R56, R57, R58, R65, R74, R75, R76, R77, R78, R79, R80, R81, R103, R104, R105, R106, R107, R108, R109, R110, R129, R130, R131, R132, R133, R134, R135, R136, R158, R159, R160, R161, R162, R163, R164, R165, R184, R185, R186, R187, R188, R189, R190, R191, R213, R214, R215, R216, R217, R218, R219, R220, R239, R240, R241, R242, R243, R244, R245, R246, R268, R269, R270, R271, R272, R273, R274, R275, R294, R295, R296, R297, R298, R299, R300, R301, R323, R324, R325, R326, R327, R328, R329, R330: 10Ω; 0402-TIGHT
R45, R46, R47, R48, R55, R82, R83, R84, R85, R92, R137, R138, R139, R140, R147, R192, R193, R194, R195, R202, R247, R248, R249, R250, R257, R302, R303, R304, R305, R312: 220; 0603
R49, R50, R86, R87, R141, R142, R196, R197, R251, R252, R306, R307: 5.1k; 0402-TIGHT
R51, R52, R88, R89, R143, R144, R198, R199, R253, R254, R308, R309: 2.2k; 0402-TIGHT
R53, R54, R90, R91, R145, R146, R200, R201, R255, R256, R310, R311: 100; 0603
S1, S7, S11, S15, S19, S23: Reset; TACTILE_SWITCH_SMD_5.2MM
S2, S4, S5, S6, S9, S10, S13, S14, S17, S18, S21, S22: DNP; TACTILE_SWITCH_PTH_RIGHT_ANGLE
S3, S8, S12, S16, S20, S24: User; TACTILE_SWITCH_SMD_5.2MM
TP1, TP14, TP22, TP30, TP38, TP46: I2C_SCK; TP_15TH
TP2, TP15, TP23, TP31, TP39, TP47: I2C_SDA; TP_15TH
TP3, TP5, TP17, TP25, TP33, TP41: SWDIO/TMS; TP_15TH
TP4, TP16, TP24, TP32, TP40, TP48: MCLK; TP_15TH
TP6, TP10, TP18, TP26, TP34, TP42: SWCK/TCK; TP_15TH
TP7, TP11, TP19, TP27, TP35, TP43: TDO; TP_15TH
TP8, TP12, TP20, TP28, TP36, TP44: TDI; TP_15TH
TP9, TP13, TP21, TP29, TP37, TP45: NRESET; TP_15TH
U1, U5, U13, U14, U20, U21, U27, U28, U34, U35, U41, U42: LM1117; SOT223
U2, U3, U15, U22, U29, U36: ATSAMS70N20A-AN; LQFP100
U4, U11, U18, U25, U32, U39: LMV324; SO14
U6, U9, U16, U23, U30, U37: 6N138M; 8-SMD
U7, U10, U17, U24, U31, U38: ADAU1328; LQFP-48
U8, U12, U19, U26, U33, U40: SN74AHC1G125; SOT23-5
U$1, U$4, U$73, U$193, U$267, U$326, U$400, U$459, U$533, U$592, U$666, U$725: QWIIC_5MM
U$2, U$5, U$268, U$401, U$534, U$667: STAT0
U$3, U$264, U$397, U$530, U$663, U$796: GND_0
U$6, U$42, U$269, U$402, U$535, U$668: #USER#0
U$7, U$90, U$270, U$403, U$536, U$669: #RESET#0
U$8, U$9, U$100, U$101, U$271, U$272, U$404, U$405, U$537, U$538, U$670, U$671: ROBERTSONICS0
U$10, U$115, U$167, U$229, U$275, U$362, U$408, U$495, U$541, U$628, U$674, U$761: #2L#0
U$11, U$114, U$274, U$407, U$540, U$673: #1L#0
U$12, U$109, U$120, U$226, U$273, U$359, U$406, U$492, U$539, U$625, U$672, U$758: #1R#0
U$13, U$125, U$276, U$409, U$542, U$675: #2R#0
U$14, U$126, U$277, U$410, U$543, U$676: #3R#0
U$15, U$127, U$278, U$411, U$544, U$677: #3L#0
U$16, U$128, U$279, U$412, U$545, U$678: #4L#0
U$17, U$129, U$280, U$413, U$546, U$679: #4R#0
U$18, U$217, U$350, U$483, U$616, U$749: #4#3
U$19, U$218, U$351, U$484, U$617, U$750: #2#5
U$20, U$107, U$130, U$201, U$281, U$334, U$414, U$467, U$547, U$600, U$680, U$733: AUDIO_OUT0
U$21, U$46, U$108, U$123, U$131, U$157, U$202, U$207, U$282, U$307, U$335, U$340, U$415, U$440, U$468, U$473, U$548, U$573, U$601, U$606, U$681, U$706, U$734, U$739: IN0
U$22, U$106, U$132, U$200, U$283, U$333, U$416, U$466, U$549, U$599, U$682, U$732: TRIGGER_IN0
U$23, U$85, U$134, U$195, U$285, U$328, U$418, U$461, U$551, U$594, U$684, U$727: #GND#0
U$24, U$135, U$286, U$419, U$552, U$685: #1#0
U$25, U$186, U$319, U$452, U$585, U$718: SERIAL3
U$26, U$60, U$161, U$187, U$311, U$320, U$444, U$453, U$577, U$586, U$710, U$719: SUPER0
U$27, U$99, U$265, U$266, U$398, U$399, U$531, U$532, U$664, U$665, U$797, U$798: VIN_5#10_VDC0
U$28, U$84, U$133, U$194, U$284, U$327, U$417, U$460, U$550, U$593, U$683, U$726: #AGND#0
U$29, U$136, U$287, U$420, U$553, U$686: #2#0
U$30, U$137, U$288, U$421, U$554, U$687: #3#0
U$31, U$56, U$117, U$138, U$159, U$223, U$289, U$309, U$356, U$422, U$442, U$489, U$555, U$575, U$622, U$688, U$708, U$755: #4#0
U$32, U$58, U$118, U$139, U$160, U$224, U$290, U$310, U$357, U$423, U$443, U$490, U$556, U$576, U$623, U$689, U$709, U$756: #5#0
U$33, U$140, U$291, U$424, U$557, U$690: #6#0
U$34, U$142, U$292, U$425, U$558, U$691: #7#0
U$35, U$143, U$293, U$426, U$559, U$692: #8#0
U$36, U$144, U$294, U$427, U$560, U$693: #9#0
U$37, U$145, U$295, U$428, U$561, U$694: #10#0
U$38, U$146, U$296, U$429, U$562, U$695: #11#0
U$39, U$147, U$297, U$430, U$563, U$696: #12#0
U$40, U$263, U$396, U$529, U$662, U$795: #PLAYING#30
U$41, U$112, U$211, U$214, U$344, U$347, U$477, U$480, U$610, U$613, U$743, U$746: #3V3#0
U$43, U$148, U$298, U$431, U$564, U$697: #13#0
U$44, U$212, U$345, U$478, U$611, U$744: #3V3_A#0
U$45, U$122, U$156, U$206, U$306, U$339, U$439, U$472, U$572, U$605, U$705, U$738: MIDI0
U$47, U$124, U$158, U$208, U$308, U$341, U$441, U$474, U$574, U$607, U$707, U$740: OUT0
U$48, U$149, U$299, U$432, U$565, U$698: #14#0
U$49, U$150, U$300, U$433, U$566, U$699: #15#0
U$50, U$151, U$301, U$434, U$567, U$700: #16#0
U$51, U$152, U$302, U$435, U$568, U$701: A10
U$52, U$153, U$303, U$436, U$569, U$702: A20
U$53, U$154, U$304, U$437, U$570, U$703: A30
U$54, U$155, U$305, U$438, U$571, U$704: A40
U$55, U$220, U$353, U$486, U$619, U$752: #5#6
U$57, U$221, U$354, U$487, U$620, U$753: #2#6
U$59, U$222, U$355, U$488, U$621, U$754: #4#6
U$61, U$110, U$184, U$203, U$317, U$336, U$450, U$469, U$583, U$602, U$716, U$735: #GND#1
U$62, U$68, U$179, U$188, U$312, U$321, U$445, U$454, U$578, U$587, U$711, U$720: TRIGGER0
U$63, U$69, U$180, U$189, U$313, U$322, U$446, U$455, U$579, U$588, U$712, U$721: TSUNAMI0
U$64, U$70, U$181, U$190, U$314, U$323, U$447, U$456, U$580, U$589, U$713, U$722: W0
U$65, U$71, U$182, U$191, U$315, U$324, U$448, U$457, U$581, U$590, U$714, U$723: A0
U$66, U$72, U$183, U$192, U$316, U$325, U$449, U$458, U$582, U$591, U$715, U$724: V0
U$67, U$111, U$185, U$204, U$318, U$337, U$451, U$470, U$584, U$603, U$717, U$736: #VIN#2
U$74, U$235, U$368, U$501, U$634, U$767: #16#5
U$75, U$236, U$369, U$502, U$635, U$768: #15#17
U$76, U$237, U$370, U$503, U$636, U$769: #14#17
U$77, U$238, U$371, U$504, U$637, U$770: #13#17
U$78, U$239, U$372, U$505, U$638, U$771: #12#17
U$79, U$240, U$373, U$506, U$639, U$772: #11#17
U$80, U$241, U$374, U$507, U$640, U$773: #10#17
U$81, U$242, U$375, U$508, U$641, U$774: #9#17
U$82, U$243, U$376, U$509, U$642, U$775: #8#17
U$83, U$244, U$377, U$510, U$643, U$776: #7#17
U$86, U$251, U$384, U$517, U$650, U$783: CS17
U$87, U$252, U$385, U$518, U$651, U$784: BCLK19
U$88, U$253, U$386, U$519, U$652, U$785: COPI18
U$89, U$254, U$387, U$520, U$653, U$786: TDMO20
U$91, U$255, U$388, U$521, U$654, U$787: SPCK22
U$92, U$256, U$389, U$522, U$655, U$788: TDMI25
U$93, U$257, U$390, U$523, U$656, U$789: LRCK24
U$94, U$258, U$391, U$524, U$657, U$790: CIPO23
U$95, U$259, U$392, U$525, U$658, U$791: APDM26
U$96, U$260, U$393, U$526, U$659, U$792: #AGND#27
U$97, U$261, U$394, U$527, U$660, U$793: #AGND#28
U$98, U$262, U$395, U$528, U$661, U$794: #PLAYING#29
U$102, U$196, U$329, U$462, U$595, U$728: A117
U$103, U$197, U$330, U$463, U$596, U$729: A2118
U$104, U$198, U$331, U$464, U$597, U$730: A32119
U$105, U$199, U$332, U$465, U$598, U$731: A432120
U$113, U$205, U$338, U$471, U$604, U$737: #I2C#6
U$116, U$215, U$348, U$481, U$614, U$747: #1L#3
U$119, U$225, U$358, U$491, U$624, U$757: #1L#6
U$121, U$227, U$360, U$493, U$626, U$759: #1R#2
U$141, U$209, U$342, U$475, U$608, U$741: SFE_LOGO_NAME_FLAME_.1
U$162, U$213, U$346, U$479, U$612, U$745: #3V3_A#4
U$163, U$210, U$343, U$476, U$609, U$742: #3V3_QWIIC#0
U$164, U$216, U$349, U$482, U$615, U$748: #1R#3
U$165, U$219, U$352, U$485, U$618, U$751: #5#5
U$166, U$228, U$361, U$494, U$627, U$760: #1L#2
U$168, U$230, U$363, U$496, U$629, U$762: #2R#3
U$169, U$231, U$364, U$497, U$630, U$763: #3L#3
U$170, U$232, U$365, U$498, U$631, U$764: #3R#4
U$171, U$233, U$366, U$499, U$632, U$765: #4L#4
U$172, U$234, U$367, U$500, U$633, U$766: #4R#5
U$173, U$245, U$378, U$511, U$644, U$777: #6#17
U$174, U$246, U$379, U$512, U$645, U$778: #5#17
U$175, U$247, U$380, U$513, U$646, U$779: #4#17
U$176, U$248, U$381, U$514, U$647, U$780: #3#17
U$177, U$249, U$382, U$515, U$648, U$781: #2#17
U$178, U$250, U$383, U$516, U$649, U$782: #1#17
Y1, Y2, Y3, Y4, Y5, Y6: 11.2896 MHz; CRYSTAL-OSC-SMD-5X3

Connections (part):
1: D5.C, R82.2, U9.2
2: D8.C, R137.2, U16.2
3: D11.C, R192.2, U23.2
3.3V: 3V3_QWIIC.1, C6.1, C8.1, C10.1, C11.1, C12.1, C13.1, C15.1, C16.1, C27.1, C28.1, C36.1, C62.1, D4.4, FB3.1, I2C.2, J7.1, J9.1, JP7.VCC, R3.2, R4.2, R6.2, R9.2, R10.2, R12.2, R16.1, R18.2, R19.2, R20.2, R21.2, R22.2, R23.2, R47.2, R48.2, U1.2, U1.4, U3.5, U3.19, U3.28, U3.68, U3.81, U3.93, U6.8, U7.13, U8.5
3.3V1: 3V3_QWIIC1.1, C85.1, C89.1, C90.1, C101.1, C109.1, C110.1, C111.1, C112.1, C113.1, C114.1, C147.1, C148.1, D6.4, FB8.1, I2C1.2, J19.1, J32.1, JP1.VCC, R13.2, R24.2, R29.2, R30.2, R31.2, R32.2, R34.1, R36.2, R68.2, R69.2, R70.2, R72.2, R83.2, R84.2, R93.2, U2.5, U2.19, U2.28, U2.68, U2.81, U2.93, U9.8, U10.13, U12.5, U14.2, U14.4
3.3V2: 3V3_QWIIC2.1, C163.1, C167.1, C168.1, C179.1, C187.1, C188.1, C189.1, C190.1, C191.1, C192.1, C225.1, C226.1, D9.4, FB13.1, I2C2.2, J35.1, J48.1, JP2.VCC, R111.2, R112.2, R113.2, R114.2, R115.2, R116.2, R118.1, R120.2, R123.2, R124.2, R125.2, R127.2, R138.2, R139.2, R148.2, U15.5, U15.19, U15.28, U15.68, U15.81, U15.93, U16.8, U17.13, U19.5, U21.2, U21.4
3.3V3: 3V3_QWIIC3.1, C241.1, C245.1, C246.1, C257.1, C265.1, C266.1, C267.1, C268.1, C269.1, C270.1, C303.1, C304.1, D12.4, FB18.1, I2C3.2, J51.1, J64.1, JP3.VCC, R166.2, R167.2, R168.2, R169.2, R170.2, R171.2, R173.1, R175.2, R178.2, R179.2, R180.2, R182.2, R193.2, R194.2, R203.2, U22.5, U22.19, U22.28, U22.68, U22.81, U22.93, U23.8, U24.13, U26.5, U28.2, U28.4
3.3V4: 3V3_QWIIC4.1, C319.1, C323.1, C324.1, C335.1, C343.1, C344.1, C345.1, C346.1, C347.1, C348.1, C381.1, C382.1, D15.4, FB23.1, I2C4.2, J67.1, J80.1, JP4.VCC, R221.2, R222.2, R223.2, R224.2, R225.2, R226.2, R228.1, R230.2, R233.2, R234.2, R235.2, R237.2, R248.2, R249.2, R258.2, U29.5, U29.19, U29.28, U29.68, U29.81, U29.93, U30.8, U31.13, U33.5, U35.2, U35.4
3.3V5: 3V3_QWIIC5.1, C397.1, C401.1, C402.1, C413.1, C421.1, C422.1, C423.1, C424.1, C425.1, C426.1, C459.1, C460.1, D18.4, FB28.1, I2C5.2, J83.1, J96.1, JP5.VCC, R276.2, R277.2, R278.2, R279.2, R280.2, R281.2, R283.1, R285.2, R288.2, R289.2, R290.2, R292.2, R303.2, R304.2, R313.2, U36.5, U36.19, U36.28, U36.68, U36.81, U36.93, U37.8, U38.13, U40.5, U42.2, U42.4
4: D14.C, R247.2, U30.2
5: D17.C, R302.2, U37.2
56: D3.C, R45.2, U6.2
ADC1LN: C69.1, U7.40
ADC1LN1: C139.1, U10.40
ADC1LN2: C217.1, U17.40
ADC1LN3: C295.1, U24.40
ADC1LN4: C373.1, U31.40
ADC1LN5: C451.1, U38.40
ADC1LP: C70.1, U7.39
ADC1LP1: C140.1, U10.39
ADC1LP2: C218.1, U17.39
ADC1LP3: C296.1, U24.39
ADC1LP4: C374.1, U31.39
ADC1LP5: C452.1, U38.39
ADC2LN: C71.1, U7.44
ADC2LN1: C141.1, U10.44
ADC2LN2: C219.1, U17.44
ADC2LN3: C297.1, U24.44
ADC2LN4: C375.1, U31.44
ADC2LN5: C453.1, U38.44
ADC2LP: C72.1, U7.43
ADC2LP1: C142.1, U10.43
ADC2LP2: C220.1, U17.43
ADC2LP3: C298.1, U24.43
ADC2LP4: C376.1, U31.43
ADC2LP5: C454.1, U38.43
AGND: C3.2, C5.2, C29.2, C30.2, C31.2, C32.2, C37.2, C38.2, C47.2, C48.2, C49.2, C50.2, C51.2, C52.2, C53.2, C54.2, C55.2, C56.2, C57.2, C58.2, C59.2, C60.2, C73.1, C74.1, C75.1, C76.1, C77.1, C78.1, C79.1, C80.1, FB4.2, J14.2, J14.4, J14.6, J14.8, J14.10, J14.12, J14.14, J14.16, J14.18, J14.20, J17.1, R7.1, U4.11, U7.1, U7.4, U7.32, U7.34, U7.36
AGND1: C86.2, C87.2, C91.2, C92.2, C93.2, C94.2, C95.1, C96.1, C97.1, C98.1, C99.1, C100.1, C117.1, C118.1, C119.2, C120.2, C121.2, C122.2, C123.2, C124.2, C125.2, C126.2, C127.2, C128.2, C129.2, C130.2, C131.2, C132.2, C143.2, C144.2, FB10.2, J5.2, J5.4, J5.6, J5.8, J5.10, J5.12, J5.14, J5.16, J5.18, J5.20, J29.1, R66.1, U10.1, U10.4, U10.32, U10.34, U10.36, U11.11
AGND2: C164.2, C165.2, C169.2, C170.2, C171.2, C172.2, C173.1, C174.1, C175.1, C176.1, C177.1, C178.1, C195.1, C196.1, C197.2, C198.2, C199.2, C200.2, C201.2, C202.2, C203.2, C204.2, C205.2, C206.2, C207.2, C208.2, C209.2, C210.2, C221.2, C222.2, FB15.2, J33.2, J33.4, J33.6, J33.8, J33.10, J33.12, J33.14, J33.16, J33.18, J33.20, J45.1, R121.1, U17.1, U17.4, U17.32, U17.34, U17.36, U18.11
AGND3: C242.2, C243.2, C247.2, C248.2, C249.2, C250.2, C251.1, C252.1, C253.1, C254.1, C255.1, C256.1, C273.1, C274.1, C275.2, C276.2, C277.2, C278.2, C279.2, C280.2, C281.2, C282.2, C283.2, C284.2, C285.2, C286.2, C287.2, C288.2, C299.2, C300.2, FB20.2, J49.2, J49.4, J49.6, J49.8, J49.10, J49.12, J49.14, J49.16, J49.18, J49.20, J61.1, R176.1, U24.1, U24.4, U24.32, U24.34, U24.36, U25.11
AGND4: C320.2, C321.2, C325.2, C326.2, C327.2, C328.2, C329.1, C330.1, C331.1, C332.1, C333.1, C334.1, C351.1, C352.1, C353.2, C354.2, C355.2, C356.2, C357.2, C358.2, C359.2, C360.2, C361.2, C362.2, C363.2, C364.2, C365.2, C366.2, C377.2, C378.2, FB25.2, J65.2, J65.4, J65.6, J65.8, J65.10, J65.12, J65.14, J65.16, J65.18, J65.20, J77.1, R231.1, U31.1, U31.4, U31.32, U31.34, U31.36, U32.11
AGND5: C398.2, C399.2, C403.2, C404.2, C405.2, C406.2, C407.1, C408.1, C409.1, C410.1, C411.1, C412.1, C429.1, C430.1, C431.2, C432.2, C433.2, C434.2, C435.2, C436.2, C437.2, C438.2, C439.2, C440.2, C441.2, C442.2, C443.2, C444.2, C455.2, C456.2, FB30.2, J81.2, J81.4, J81.6, J81.8, J81.10, J81.12, J81.14, J81.16, J81.18, J81.20, J93.1, R286.1, U38.1, U38.4, U38.32, U38.34, U38.36, U39.11
AIN1L: C63.2, J14.17
AIN1L1: C133.2, J5.17
AIN1L2: C211.2, J33.17
AIN1L3: C289.2, J49.17
AIN1L4: C367.2, J65.17
AIN1L5: C445.2, J81.17
AIN1R: C66.2, J14.19
AIN1R1: C136.2, J5.19
AIN1R2: C214.2, J33.19
AIN1R3: C292.2, J49.19
AIN1R4: C370.2, J65.19
AIN1R5: C448.2, J81.19
AOUT1L: C46.1, C47.1, R37.2
AOUT1L1: C119.1, C156.1, R74.2
AOUT1L2: C197.1, C234.1, R129.2
AOUT1L3: C275.1, C312.1, R184.2
AOUT1L4: C353.1, C390.1, R239.2
AOUT1L5: C431.1, C468.1, R294.2
AOUT1R: C45.1, C48.1, R38.2
AOUT1R1: C120.1, C155.1, R75.2
AOUT1R2: C198.1, C233.1, R130.2
AOUT1R3: C276.1, C311.1, R185.2
AOUT1R4: C354.1, C389.1, R240.2
AOUT1R5: C432.1, C467.1, R295.2
AOUT2L: C44.2, J14.5
AOUT2L1: C154.2, J5.5
AOUT2L2: C232.2, J33.5
AOUT2L3: C310.2, J49.5
AOUT2L4: C388.2, J65.5
AOUT2L5: C466.2, J81.5
AOUT2R: C43.1, C50.1, R40.2
AOUT2R1: C122.1, C153.1, R77.2
AOUT2R2: C200.1, C231.1, R132.2
AOUT2R3: C278.1, C309.1, R187.2
AOUT2R4: C356.1, C387.1, R242.2
AOUT2R5: C434.1, C465.1, R297.2
AOUT3L: C42.2, J14.9
AOUT3L1: C152.2, J5.9
AOUT3L2: C230.2, J33.9
AOUT3L3: C308.2, J49.9
AOUT3L4: C386.2, J65.9
AOUT3L5: C464.2, J81.9
AOUT3R: C41.1, C52.1, R42.2
AOUT3R1: C124.1, C151.1, R79.2
AOUT3R2: C202.1, C229.1, R134.2
AOUT3R3: C280.1, C307.1, R189.2
AOUT3R4: C358.1, C385.1, R244.2
AOUT3R5: C436.1, C463.1, R299.2
AOUT4L: C40.1, C53.1, R43.2
AOUT4L1: C125.1, C150.1, R80.2
AOUT4L2: C203.1, C228.1, R135.2
AOUT4L3: C281.1, C306.1, R190.2
AOUT4L4: C359.1, C384.1, R245.2
AOUT4L5: C437.1, C462.1, R300.2
AOUT4R: C39.1, C54.1, R44.2
AOUT4R1: C126.1, C149.1, R81.2
AOUT4R2: C204.1, C227.1, R136.2
AOUT4R3: C282.1, C305.1, R191.2
AOUT4R4: C360.1, C383.1, R246.2
AOUT4R5: C438.1, C461.1, R301.2
APDN: J13.9, U3.70, U7.10
APDN1: J30.9, U2.70, U10.10
APDN2: J46.9, U15.70, U17.10
APDN3: J62.9, U22.70, U24.10
APDN4: J78.9, U29.70, U31.10
APDN5: J94.9, U36.70, U38.10
BCLK: J13.6, U3.11, U7.17, U7.21
BCLK1: J30.6, U2.11, U10.17, U10.21
BCLK2: J46.6, U15.11, U17.17, U17.21
BCLK3: J62.6, U22.11, U24.17, U24.21
BCLK4: J78.6, U29.11, U31.17, U31.21
BCLK5: J94.6, U36.11, U38.17, U38.21
BLUE_LED: R54.1, U3.31
BLUE_LED1: R91.1, U2.31
BLUE_LED2: R146.1, U15.31
BLUE_LED3: R201.1, U22.31
BLUE_LED4: R256.1, U29.31
BLUE_LED5: R311.1, U36.31
CC1: J16.A5, R50.2
CC2: J16.B5, R49.2
CC3: J27.B5, R86.2
CC4: J27.A5, R87.2
CC5: J43.B5, R141.2
CC6: J43.A5, R142.2
CC7: J59.B5, R196.2
CC8: J59.A5, R197.2
CC9: J75.B5, R251.2
CC10: J75.A5, R252.2
CC11: J91.B5, R306.2
CC12: J91.A5, R307.2
CM_1.5V: C55.1, U4.3, U4.5, U4.10, U4.12, U7.38
CM_1.5V1: C127.1, U10.38, U11.3, U11.5, U11.10, U11.12
CM_1.5V2: C205.1, U17.38, U18.3, U18.5, U18.10, U18.12
CM_1.5V3: C283.1, U24.38, U25.3, U25.5, U25.10, U25.12
CM_1.5V4: C361.1, U31.38, U32.3, U32.5, U32.10, U32.12
CM_1.5V5: C439.1, U38.38, U39.3, U39.5, U39.10, U39.12
DBUG: J3.1, U3.72
DBUG1: J23.1, U2.72
DBUG2: J39.1, U15.72
DBUG3: J55.1, U22.72
DBUG4: J71.1, U29.72
DBUG5: J87.1, U36.72
DGND: C1.2, C2.2, C4.2, C6.2, C7.2, C8.2, C9.2, C10.2, C11.2, C12.2, C13.2, C14.2, C15.2, C16.2, C17.2, C18.2, C19.2, C20.2, C21.2, C22.2, C23.2, C24.2, C25.2, C26.2, C27.2, C28.2, C36.2, C62.2, FB4.1, J2.1, J2.2, J4.1, J9.3, J9.5, J9.9, J10.2, J10.4, J10.6, J10.8, J10.10, J10.12, J10.14, J10.16, J11.2, J11.4, J11.6, J11.8, J11.10, J11.12, J11.14, J11.16, J13.10, J15.4, J16.GND, J16.GND2, J18.6, JP7.GND, JP7.GND1, JP7.GND3, R2.1, R8.1, R17.1, R49.1, R50.1, S1.1, S2.1, S3.1, S4.1, U3.3, U3.6, U3.7, U3.8, U3.10, U3.29, U3.67, U6.5, U7.12, U7.25, U8.1, U8.3, Y1.2, Y1.4
DGND1: C64.2, C65.2, C81.2, C82.2, C83.2, C84.2, C85.2, C88.2, C89.2, C90.2, C101.2, C102.2, C103.2, C104.2, C105.2, C106.2, C107.2, C108.2, C109.2, C110.2, C111.2, C112.2, C113.2, C114.2, C115.2, C116.2, C147.2, C148.2, FB10.1, J20.2, J20.4, J20.6, J20.8, J20.10, J20.12, J20.14, J20.16, J21.2, J21.4, J21.6, J21.8, J21.10, J21.12, J21.14, J21.16, J22.4, J26.1, J26.2, J27.GND, J27.GND2, J28.1, J30.10, J31.6, J32.3, J32.5, J32.9, JP1.GND, JP1.GND1, JP1.GND3, R33.1, R67.1, R73.1, R86.1, R87.1, S5.1, S6.1, S7.1, S8.1, U2.3, U2.6, U2.7, U2.8, U2.10, U2.29, U2.67, U9.5, U10.12, U10.25, U12.1, U12.3, Y2.2, Y2.4
DGND2: C157.2, C158.2, C159.2, C160.2, C161.2, C162.2, C163.2, C166.2, C167.2, C168.2, C179.2, C180.2, C181.2, C182.2, C183.2, C184.2, C185.2, C186.2, C187.2, C188.2, C189.2, C190.2, C191.2, C192.2, C193.2, C194.2, C225.2, C226.2, FB15.1, J36.2, J36.4, J36.6, J36.8, J36.10, J36.12, J36.14, J36.16, J37.2, J37.4, J37.6, J37.8, J37.10, J37.12, J37.14, J37.16, J38.4, J42.1, J42.2, J43.GND, J43.GND2, J44.1, J46.10, J47.6, J48.3, J48.5, J48.9, JP2.GND, JP2.GND1, JP2.GND3, R117.1, R122.1, R128.1, R141.1, R142.1, S9.1, S10.1, S11.1, S12.1, U15.3, U15.6, U15.7, U15.8, U15.10, U15.29, U15.67, U16.5, U17.12, U17.25, U19.1, U19.3, Y3.2, Y3.4
DGND3: C235.2, C236.2, C237.2, C238.2, C239.2, C240.2, C241.2, C244.2, C245.2, C246.2, C257.2, C258.2, C259.2, C260.2, C261.2, C262.2, C263.2, C264.2, C265.2, C266.2, C267.2, C268.2, C269.2, C270.2, C271.2, C272.2, C303.2, C304.2, FB20.1, J52.2, J52.4, J52.6, J52.8, J52.10, J52.12, J52.14, J52.16, J53.2, J53.4, J53.6, J53.8, J53.10, J53.12, J53.14, J53.16, J54.4, J58.1, J58.2, J59.GND, J59.GND2, J60.1, J62.10, J63.6, J64.3, J64.5, J64.9, JP3.GND, JP3.GND1, JP3.GND3, R172.1, R177.1, R183.1, R196.1, R197.1, S13.1, S14.1, S15.1, S16.1, U22.3, U22.6, U22.7, U22.8, U22.10, U22.29, U22.67, U23.5, U24.12, U24.25, U26.1, U26.3, Y4.2, Y4.4
DGND4: C313.2, C314.2, C315.2, C316.2, C317.2, C318.2, C319.2, C322.2, C323.2, C324.2, C335.2, C336.2, C337.2, C338.2, C339.2, C340.2, C341.2, C342.2, C343.2, C344.2, C345.2, C346.2, C347.2, C348.2, C349.2, C350.2, C381.2, C382.2, FB25.1, J68.2, J68.4, J68.6, J68.8, J68.10, J68.12, J68.14, J68.16, J69.2, J69.4, J69.6, J69.8, J69.10, J69.12, J69.14, J69.16, J70.4, J74.1, J74.2, J75.GND, J75.GND2, J76.1, J78.10, J79.6, J80.3, J80.5, J80.9, JP4.GND, JP4.GND1, JP4.GND3, R227.1, R232.1, R238.1, R251.1, R252.1, S17.1, S18.1, S19.1, S20.1, U29.3, U29.6, U29.7, U29.8, U29.10, U29.29, U29.67, U30.5, U31.12, U31.25, U33.1, U33.3, Y5.2, Y5.4
DGND5: C391.2, C392.2, C393.2, C394.2, C395.2, C396.2, C397.2, C400.2, C401.2, C402.2, C413.2, C414.2, C415.2, C416.2, C417.2, C418.2, C419.2, C420.2, C421.2, C422.2, C423.2, C424.2, C425.2, C426.2, C427.2, C428.2, C459.2, C460.2, FB30.1, J84.2, J84.4, J84.6, J84.8, J84.10, J84.12, J84.14, J84.16, J85.2, J85.4, J85.6, J85.8, J85.10, J85.12, J85.14, J85.16, J86.4, J90.1, J90.2, J91.GND, J91.GND2, J92.1, J94.10, J95.6, J96.3, J96.5, J96.9, JP5.GND, JP5.GND1, JP5.GND3, R282.1, R287.1, R293.1, R306.1, R307.1, S21.1, S22.1, S23.1, S24.1, U36.3, U36.6, U36.7, U36.8, U36.10, U36.29, U36.67, U37.5, U38.12, U38.25, U40.1, U40.3, Y6.2, Y6.4
GREEN_LED: R53.1, U3.27
GREEN_LED1: R90.1, U2.27
GREEN_LED2: R145.1, U15.27
GREEN_LED3: R200.1, U22.27
GREEN_LED4: R255.1, U29.27
GREEN_LED5: R310.1, U36.27
I2C_SCK: J4.4, R52.1, TP1.1, U3.55
I2C_SCK1: J28.4, R89.1, TP14.1, U2.55
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

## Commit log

2021-07-19 Bringing it all in!
    [SparkFun_Tsunami_Qwiic-Panel.brd, SparkFun_Tsunami_Qwiic.brd, SparkFun_Tsunami_Qwiic.sch]
2021-08-03 example WAV files for Arduino Library examples
2022-02-23 Single buffer gate change
    drop in replacement for U8 single buffer IC, with new PROD_ID
    [SparkFun_Tsunami_Qwiic.brd, SparkFun_Tsunami_Qwiic.sch]
2022-02-23 Update Prod_ID for U8 (buffer IC) on panel
    [SparkFun_Tsunami_Qwiic-Panel.brd]
2022-10-31 Added SCH note about U3 population
    -We are now making this board with two separate SKUs. The only difference in BOM is on U3.
    -Also exported updated SCH as PDF for docs.
    [SparkFun_Tsunami_Qwiic.brd, SparkFun_Tsunami_Qwiic.sch]

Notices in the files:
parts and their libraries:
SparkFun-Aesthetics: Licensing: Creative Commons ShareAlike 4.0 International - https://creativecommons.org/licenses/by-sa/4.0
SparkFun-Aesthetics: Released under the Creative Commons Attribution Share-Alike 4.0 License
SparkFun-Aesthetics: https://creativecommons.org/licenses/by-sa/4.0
